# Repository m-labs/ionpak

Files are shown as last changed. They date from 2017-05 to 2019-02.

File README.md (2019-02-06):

ionpak
======

A modern, low-cost universal controller for hot-cathode ionization vacuum gauges.

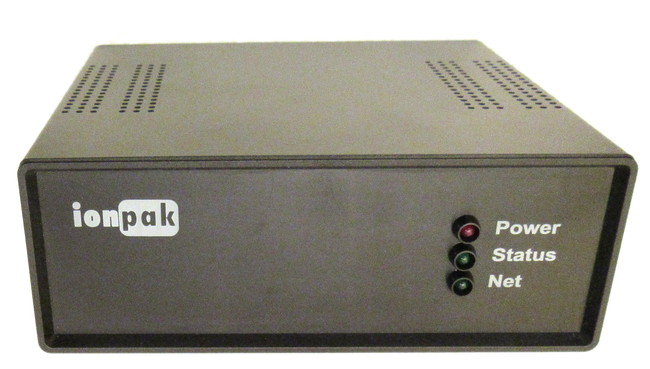
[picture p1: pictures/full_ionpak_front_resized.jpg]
ionpak picture


Why?
----

Many physics experiments require a good vacuum and therefore tools to diagnose vacuum-related problems. Ionization gauges provide a way to measure pressures in the medium to ultra-high vacuum regimes.

While the gauges themselves can be procured quite easily, the controller situation is more problematic. Existing commercial and DIY solutions have one or more of the following issues:

 * expensive
 * proprietary
 * poor performance at low (pA) collector currents
 * designed with obsolete components and overly bulky
 * lack of gauge voltage/current programmability
 * no/poor connectivity to a logging database
 * poor design and construction

The ionpak features:

 * a single-board low-cost design with modern components
 * open hardware and software
 * sub-pA electrometer performance
 * configurable voltages and emission current to adapt to various gauges
 * Ethernet connectivity

Where to find ionization vacuum gauges?
---------------------------------------

For medium and high vacuum, Chinese gauges can be ordered on Taobao under references ZJ-27 and ZJ-10. The Chinese for ionization gauge is 电离规. Those gauges have a simple construction and an extremely low cost, under USD 10 for glass tubulated models (requires flameworking) and a few times that price for flange-mounted ones. Those manufactured by [Chengdu Zhenghua](http://www.zhvacuum.com) appear to work satisfactorily, and glass gauges arrive sealed under vacuum (around 10⁻⁵ to 10⁻⁶ mbar) so they can be tested immediately. Ceramic sockets for the gauges can often be ordered from the same Taobao vendor.

For ultra-high vacuum, you can use G8130 from KJLC, which is pricy but of excellent quality. There is a lower-cost Bayard-Alpert Chinese gauge ZJ-12, of dubious quality for those pressure ranges, and with 2.5x less sensitivity than the KJLC part.

A low-cost source of quality UHV gauges remains to be found. You can try eBay, but the condition of the items is highly random.

How to connect the gauge?
-------------------------

The collector must be connected with a shielded (e.g. coaxial) cable. If the gauge has a metallic body (e.g. gauges mounted on CF flanges), connect the shield of the cable to the body, so that current from the high voltage electrodes will not leak into the collector electrode. This should not cause any ground loop in your system, as the gauge circuits inside the ionpak are galvanically isolated from its power input and from its Ethernet connector.

If a single cable is used for the filament and anode connections, the anode wire must be particularly well insulated from the filament wires, to avoid leakage currents that can be significant when the gauge is operated with a low emission (100µA or less) and influence the measurement result.

"Domino" terminal blocks from the local hardware store, with the plastic removed, can be used to connect the cables to the pins of CF-flanged gauges. Female circular contacts, such as Amphenol AT62-16-0122, are a nicer alternative but are slightly harder to find.

For baked systems, use PTFE insulated cables that can withstand 200°C. Operating the gauge during bake-out can remove the need to degas it (see the paper [Comments on the stability of B-A ionization gages](https://www.nist.gov/sites/default/files/documents/calibrations/jv13-2.pdf)).

It is a good idea to attach the cables to the vacuum system with a strap to avoid damaging the gauge by accidentally pulling on the cables, and to place a cover onto the pins to reduce the electrical shock hazard from the high voltage. Preferably those items should be made of metal so that they can be left on during bakeout.

Using the ionpak
----------------
Connect the ionpak to a firewalled Ethernet network *only*, as it does not provide authentication over the network.

The ionpak has a static IP address that defaults to `192.168.69.1`. It has a self-explanatory web interface that you can access by pointing your browser to [http://192.168.69.1](http://192.168.69.1). By default, the controller is disabled and the ionpak will not produce any output voltages; use the web interface to input your gauge settings and enable the controller.

The IP address, along with all the other configuration options, can be reset to the defaults by holding the pushbutton while the ionpak is powering up. The status LED will flash rapidly to acknowledge the configuration reset.

In addition to displaying its measurement results in the web interface, the ionpak exports them in the JSON format. The results are very straightforward to access from Python:

```
>>> import requests
>>> import json
>>> json.loads(requests.get("http://192.168.69.1/measure.json").text)
{'pressure': 3.8e-06, 'current': 3.357e-08}
```

In the JSON document, `pressure` is expressed in millibars and `current` (through the collector input) is expressed in amperes.

Warning
-------

Ionization gauges use dangerous voltages and the ionpak is capable of delivering a lethal amount of power. Be careful and use at your own risk.

Building and loading the firmware
---------------------------------

```sh
cd firmware
cargo build --release
openocd -f openocd.cfg
```

License
-------

Copyright 2017 M-Labs Limited.

License TBD, probably will be CERN OHL and GPL.

Pictures in the ``pictures`` folder, except ``proto_rev1.jpg``, are copyright Michelle Poon and not free.

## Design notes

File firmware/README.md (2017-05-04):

ionpak
======

A modern, low-cost universal controller for ionization vacuum gauges.

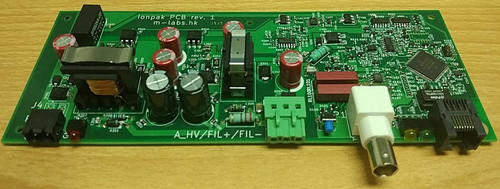
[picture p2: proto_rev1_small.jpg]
Prototype picture


Building and loading the firmware
---------------------------------

```sh
openocd -f support/openocd.cfg
xargo build --release
arm-none-eabi-gdb -x support/load.gdb target/thumbv7em-none-eabihf/release/ionpak-firmware
```

Flyback transformer construction
--------------------------------

TR300: Use EPCOS coilformer B66208X1010T1. Wind 5 turns on the primary and spread them across the length of the coilformer - it is particularly important that the air gap between the cores is covered by windings. Wind 70 turns on the secondary in multiple layers. As with all flyback transformers, the polarity of the windings is critical. Assemble with EPCOS cores B66317G500X127 and B66317GX127 (one half gapped core, one half ungapped core), and corresponding clips.

TR350: Use EPCOS coilformer B66206W1110T1 and cores B66311G250X127 and B66311GX127. Both the primary and the secondary have 5 turns and must be wound together, interleaving the windings. The same remarks as for TR300 apply.

Errata
------

PCB rev 1:

* R307 needs more clearance from D400
* Pins 1 and 12 of U502 need pull-downs
* Pin 1 of U501 needs pull-up
* D203 reversed polarity
* R236 and R234 are swapped
* Q301 needs to be NPN, change to BC817
* increase R307 -> 3.3Kohm and increase R300 -> 33Kohm
* C201: oscillates at 0 and 1nF, stable at 100nF
* add clamp diodes to GND on op-amp outputs to ADC when op-amp has negative supply
* R214 -> 4.7k
* LM339PT is in TSSOP package. Change for SOIC P/N
* GDT200 minimum firing voltage is too low
* the relay model should be changed to 9001-05-00. 9001-05-02 is an undocumented normally closed variant.

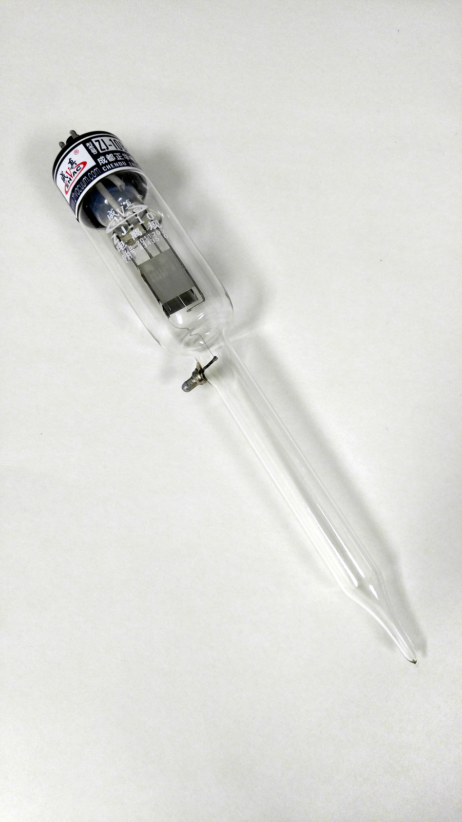
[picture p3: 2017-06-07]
pictures/zj10.jpg

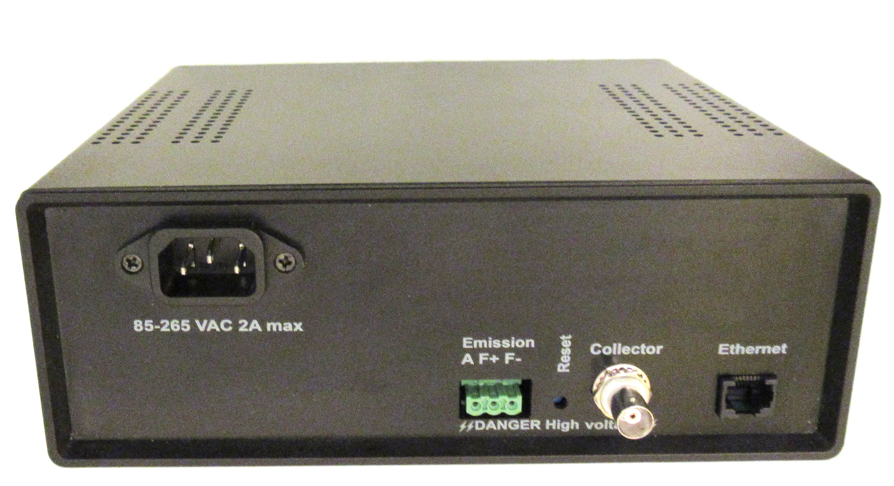
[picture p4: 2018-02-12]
pictures/full_ionpak_back.jpg

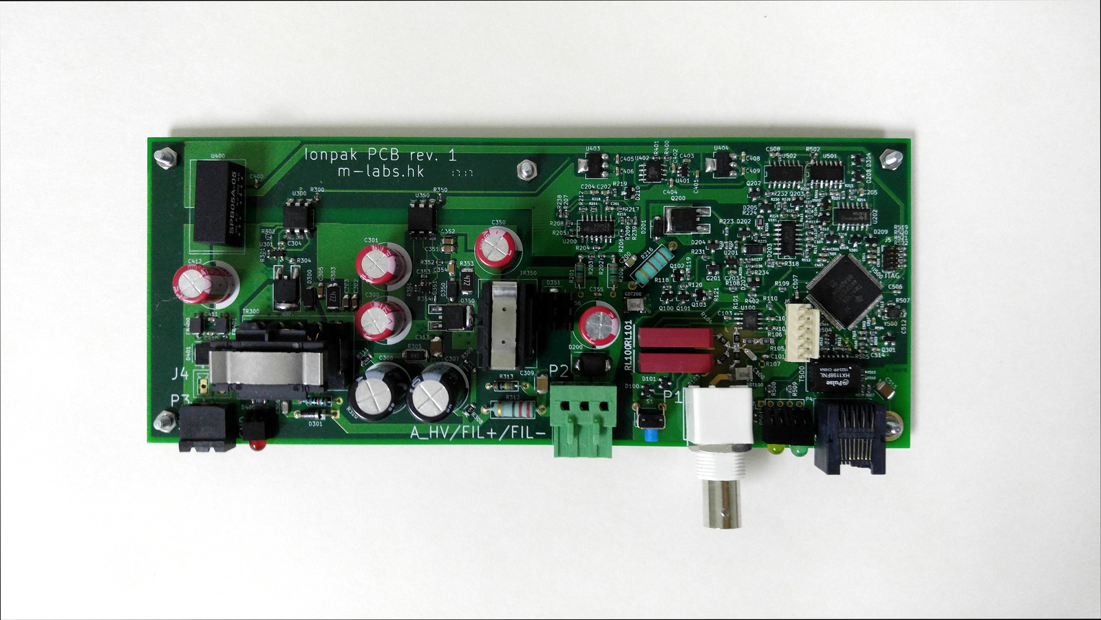
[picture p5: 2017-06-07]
pictures/pcb_1.jpg

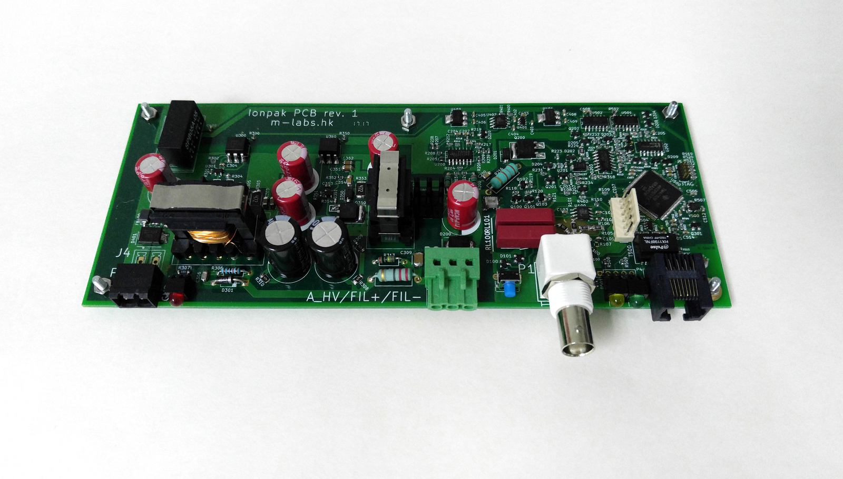
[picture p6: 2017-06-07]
pictures/pcb_2.jpg

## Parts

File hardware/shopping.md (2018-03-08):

* OLED display: https://world.taobao.com/item/539889688448.htm
* power supply modules: https://world.taobao.com/item/542931734858.htm

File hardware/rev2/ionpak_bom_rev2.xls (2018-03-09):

N | Refs | Value | Footprint | QTY | MFR | MPN | SPR | SPN
1 | C100 | 47pF/1206 | proj_footprints:C_1206_ns | 1 | AVX | 12062A101JAT2A |  | 478-1430-1-ND
2 | C102;C104;C201;C205;C304;C353;C355;C410;C411;C504;C509;C510;C505;C506;C507;C508;C503;C502;C103;C101;C414;C514 | 0.1uF | Capacitors_SMD:C_0603 | 22 | Murata | GRM188R71C104JA01D |  | 490-9731-1-ND
3 | C200 | 10000pF/1206 | Capacitors_SMD:C_1206 | 1 | Murata | GRM31BR72J103KW01L |  | 490-3512-1-ND
4 | C202;C204 | 1uF | Capacitors_SMD:C_0603 | 2 | Murata | GRM188R60J105KA01J |  | 490-6404-1-ND
5 | C302;C303;C352;C351 | 10uF/25V/1206 | Capacitors_SMD:C_1206 | 4 | Samsung Electro-Mechanics America, Inc. | CL31A106KAHNNNE |  | 1276-1075-1-ND
6 | C305;C354 | 0.1uF/100V/1206 | Capacitors_SMD:C_1206 | 2 | Murata | GRJ319R72A104KE11L |  | 490-10931-1-ND
7 | C306 | 10pF/1206 | Capacitors_SMD:C_1206 | 1 | Samsung Electro-Mechanics America, Inc. | CL31C100JIFNNNE |  | 1276-3195-1-ND
8 | C307;C308 | 10uF/450V | Capacitors_THT:C_Radial_D14_L25_P5 | 2 | Nichicon | UVR2W100MHD1TO |  | 493-12876-1-ND
9 | C309;C515 | 2200pF/2kV/1812 | Capacitors_SMD:C_1812 | 2 | Kemet | C1812C222KGRACTU |  | 399-7120-1-ND
10 | C357 | 100pF | Capacitors_SMD:C_0603 | 1 | Murata | GRM0335C1E101JA01D |  | 490-3160-1-ND
11 | C400;C402;C403;C401;C405;C406;C408;C409;C404;C511;C407 | 10uF | Capacitors_SMD:C_0603 | 11 | Murata | GRM188R60J106KE47D |  | 490-12538-1-ND
12 | C412;C350;C301;C356;C300 | 470uF/16V | Capacitors_THT:C_Radial_D13_L21_P5 | 5 | Panasonic Electronic Components | ECA-1CM471 |  | P5141-ND
13 | C500;C501 | 1000pF | Capacitors_SMD:C_0603 | 2 | Murata | GRM033R71C102KA01D |  | 490-6147-1-ND
14 | C512;C513 | 12pF | Capacitors_SMD:C_0603 | 2 | Murata | GRM0335C1E120JA01D |  | 490-3144-1-ND
15 | D200 | SMCJ7.5A | proj_footprints:DO-214AB | 1 | Diodes Incorporated | SMCJ7.5A-13-F |  | SMCJ7.5A-FDICT-ND
16 | D202 | BAS116 | proj_footprints:SOT-23 | 1 | Infineon Technologies | BAS116-7-F |  | BAS116-FDICT-ND
17 | D203 | SMAJ5.0A | proj_footprints:DO-214AC | 1 | Littelfuse Inc. | SMAJ5.0A |  | SMAJ5.0ALFCT-ND
18 | D210;D206 | BAT54S | proj_footprints:SOT-23 | 2 | ON Semiconductor | BAT54SLT1G |  | BAT54SLT1GOSCT-ND
19 | D211;D102;D306;D305;D304;D209;D208;D500;D100;D101 | BAT54 | proj_footprints:SOT-23 | 10 | ON Semiconductor | BAT54SLT1G |  | BAT54SLT1GOSCT-ND
20 | D300;D350;D201 | S1M | proj_footprints:DO-214AC | 3 | SMC Diode Solutions | S1MTR |  | 1655-1506-1-ND
21 | D301 | UF4007 | Diodes_THT:Diode_DO-41_SOD81_Horizontal_RM10 | 1 | SMC Diode Solutions | UF4007TA |  | 1655-1692-1-ND
22 | D351 | MBR1645 | proj_footprints:TO220AC | 1 | SMC Diode Solutions | MBR1060 |  | 1655-1022-ND
23 | D401 | SMCJ12A | proj_footprints:DO-214AB | 1 | Diodes Incorporated | SMCJ12A-13-F |  | SMCJ12A-FDICT-ND
24 | D501;D400 | LTL-533-11 | LEDs:LED_D3.0mm_Horizontal_O3.81mm_Z10.0mm | 2 | Lite-On Inc. | LTL-533-11 |  | 160-1977-ND
25 | D502 | LTL-523-11 | LEDs:LED_D3.0mm_Horizontal_O3.81mm_Z10.0mm | 1 | Lite-On Inc. | LTL-523-11 |  | 160-1976-ND
26 | D504 | SRV05-4 | proj_footprints:SOT-23-6 | 1 | SMC Diode Solutions | SRV05-4ATR |  | 1655-1653-1-ND
27 | FB401;FB400 | FB_10A | proj_footprints:28F0121-0SR-10 | 2 | Laird-Signal Integrity Products | 28F0121-0SR-10 |  | 240-2435-1-ND
28 | GDT100 | 2051-09 | proj_footprints:BOURNS-GDT-2051_ns | 1 | Bourns | 2051-09-SM-RPLF |  | 2051-09-SM-RPLFCT-ND
29 | GDT201 | 2035-09 | proj_footprints:BOURNS-GDT-2035TH | 1 | Bourns | 2035-09-BT1LF |  | 2035-09-BT1LFCT-ND
30 | GDT400 | 2057-35-BLF | proj_footprints:BOURNS-GDT-2035TH | 1 | Bourns | 2057-35-BLF |  | 2057-35-BLF-ND
31 | J4 | INT_PWR | Connectors_Phoenix:PhoenixContact_MCV-G_02x5.08mm_Vertical | 1 | Phoenix Contact | 1836299 |  | 277-6513-ND
32 | J5 | JTAG_ARM_10P | proj_footprints:Pin_Header_Straight_2x05_Pitch1.27mm | 1 | Sullins Connector Solutions | GRPB052VWVN-RC |  | S9015E-05-ND
33 | J6 | TTL-232R-3V3 | Pin_Headers:Pin_Header_Straight_1x06_Pitch2.54mm | 1 | Sullins Connector Solutions | SWR25X-NRTC-S06-ST-BA |  | S9414-ND
34 | J7 | EXT_LEDS | Pin_Headers:Pin_Header_Straight_1x05_Pitch2.54mm | 1 | Sullins Connector Solutions | SWR25X-NRTC-S04-ST-BA |  | S9410-ND
35 | J8 | I2C | Pin_Headers:Pin_Header_Straight_1x04_Pitch2.54mm | 1
36 | J9 | INT_FAN | Connectors_Molex:Molex_KK-6410-02_02x2.54mm_Straight | 1 | Molex | 22272021 |  | WM4111-ND
37 | L400 | SDR0503-101KL | Choke_SMD:Choke_SMD_Wuerth-WE-PD2-Typ-MS | 1 | Bourns Inc. | SDR0503-101KL |  | SDR0503-101KLCT-ND
38 | P1 | BNC | proj_footprints:bnc_90_1-1337543-0_ns | 1 | TE Connectivity AMP Connectors | 1-1337543-0 |  | A97553-ND
39 | P2 | CONN_01X03 | proj_footprints:PhoenixContact_1786417_03 | 1 | Phoenix Contact | 1786417 |  | 277-5985-ND
40 | P4 | RJ45_NO_SHIELD | proj_footprints:FCI_54601-908WPLF | 1 | Amphenol FCI | 54601-908WPLF |  | 609-5081-ND
41 | Q101;Q100;Q401 | DMG2305UX | proj_footprints:SOT-23 | 3 | Diodes Incorporated | DMG2305UX-13 |  | DMG2305UX-13DICT-ND
42 | Q103;Q102 | 2N7002 | proj_footprints:SOT-23 | 2 | Nexperia USA Inc. | 2N7002P,215 |  | 1727-4692-1-ND
43 | Q200 | FQD7N10L | proj_footprints:DPAK | 1 | Fairchild/ON Semiconductor | FQD7N10LTM |  | FQD7N10LTMCT-ND
44 | Q203;Q202;Q104 | DMN3404L | proj_footprints:SOT-23 | 3 | Diodes Incorporated | DMN3404L-7 |  | DMN3404LDICT-ND
45 | Q300;Q350 | IRFR3411 | proj_footprints:DPAK | 2 | Infineon Technologies | IRFR3411TRPBF |  | IRFR3411TRPBFCT-ND
46 | Q301 | BC817-40 | proj_footprints:SOT-23 | 1 | ON Semiconductor | BC81740MTF |  | BC81740MTFCT-ND
47 | Q400 | BC807-40 | proj_footprints:SOT-23 | 1 | ON Semiconductor | BC807-40LT1G |  | BC807-40LT1GOSCT-ND
48 | R101;R100 | 100K/1206 | proj_footprints:R_1206_ns | 2 | Yageo | RC1206JR-07100KL |  | 311-100KERCT-ND
49 | R102;R107 | 100K | Resistors_SMD:R_0603 | 2 | Yageo | RC0603JR-07100KL |  | 311-100KGRCT-ND
50 | R103 | 27K/1%/1206 | proj_footprints:R_1206_ns | 1 | Yageo | RC1206FR-0727KL |  | 311-27.0KFRCT-ND
51 | R104 | 5.1M/1%/1206 | proj_footprints:R_1206_ns | 1 | Yageo | RC1206FR-0727KL |  | 311-27.0KFRCT-ND
52 | R105;R106 | HMC1206JT500M | proj_footprints:R_1206_ns | 2 | Stackpole Electronics Inc. | HMC1206JT500M |  | HMC1206JT500MCT-ND
53 | R109;R108 | 33R | Resistors_SMD:R_0603 | 2 | Yageo | RC0603FR-0733RL |  | 311-33.0HRCT-ND
54 | R110;R208;R209;R228;R226 | 4.7K/1% | Resistors_SMD:R_0603 | 5 | Yageo | RC0603FR-074K7L |  | 311-4.70KHRCT-ND
55 | R111;R217;R218;R404;R405;R523;R524 | 1K | Resistors_SMD:R_0603 | 7 | Yageo | RC0603FR-071KL |  | 311-1.00KHRCT-ND
56 | R112;R117;R215;R221;R317;R318;R230;R223 | 10K/1% | Resistors_SMD:R_0603 | 8 | Yageo | RC0603FR-0710KL |  | 311-10.0KHRCT-ND
57 | R114;R220;R227 | 470R/1% | Resistors_SMD:R_0603 | 3 | Yageo | RC0603FR-07470RL |  | 311-470HRCT-ND
58 | R116;R229;R401;R400 | 240R/1% | Resistors_SMD:R_0603 | 4 | Yageo | RC0603FR-07240RL |  | 311-240HRCT-ND
59 | R120;R207;R210;R118;R500;R407;R408 | 33K | Resistors_SMD:R_0603 | 7 | Yageo | RC0603FR-0733KL |  | 311-33.0KHRCT-ND
60 | R121;R301;R351;R119;R501;R503;R522;R519;R520;R521;R320;R355;R510;R356 | 10K | Resistors_SMD:R_0603 | 14 | Yageo | RC0603FR-0710KL |  | 311-10.0KHRCT-ND
61 | R200;R201;R240 | 15M/1%/RNV | Resistors_ThroughHole:R_Axial_DIN0207_L6.3mm_D2.5mm_P10.16mm_Horizontal | 3 | Stackpole Electronics Inc. | RNV14FAL15M0 |  | RNV14FAL15M0CT-ND
62 | R203;R202 | 560K/1% | Resistors_SMD:R_0603 | 2 | Yageo | RC0603FR-07560KL |  | 311-560KHRCT-ND
63 | R204 | 1M/1% | Resistors_SMD:R_0603 | 1 | Yageo | RC0603FR-071ML |  | 311-1.00MHRTR-ND
64 | R206;R205 | 2.7M/1% | Resistors_SMD:R_0603 | 2 | Yageo | RC0603FR-072M7L |  | RC0603FR-072M7L-ND
65 | R212;R211;R214;R238;R239;R115;R113 | 7.5K/1% | Resistors_SMD:R_0603 | 7 | Yageo | RC0603FR-077K5L |  | 311-7.50KHRCT-ND
66 | R213;R319;R300;R350;R502;R508;R403;R509;R406 | 240R | Resistors_SMD:R_0603 | 9 | Yageo | RC0603FR-07240RL |  | 311-240HRCT-ND
67 | R216 | 180R/1W | Resistors_ThroughHole:R_Axial_DIN0414_L11.9mm_D4.5mm_P15.24mm_Horizontal | 1 | YAGEO | KNP100JR-73-180R |  | 180ACCT-ND
68 | R219 | 22K | Resistors_SMD:R_0603 | 1 | Yageo | RC0603FR-0722KL |  | 311-22.0KHRCT-ND
69 | R222;R504 | 100R | Resistors_SMD:R_0603 | 2 | Yageo | RC0603JR-07100RL |  | 311-100GRCT-ND
70 | R224 | 36R/1%/1206 | Resistors_SMD:R_1206 | 1 | Yageo | RC1206FR-0736RL |  | 311-36.0FRCT-ND
71 | R225 | 180R/1% | Resistors_SMD:R_0603 | 1 | Yageo | RC0603FR-07180RL |  | 311-180HRCT-ND
72 | R302;R352 | 3.3R | Resistors_SMD:R_0603 | 2 | Yageo | RC0603FR-073R3L |  | RC0603FR-073R3L-ND
73 | R303;R353 | 4.7K/2512 | Resistors_SMD:R_2512 | 2 | Yageo | RC2512JK-074K7L |  | YAG3405CT-ND
74 | R304;R354 | 0R | Resistors_SMD:R_0603 | 2 | Yageo | RC0603JR-070RL |  | 311-0.0GRCT-ND
75 | R305 | 2R/2512 | Resistors_SMD:R_2512 | 1 | Stackpole Electronics Inc. | RMCF2512JT2R00 |  | RMCF2512JT2R00CT-ND
76 | R306 | 10K/RNV | Resistors_ThroughHole:R_Axial_DIN0207_L6.3mm_D2.5mm_P10.16mm_Horizontal | 1 | Stackpole Electronics Inc. | RNF14FTD10K0 |  | RNF14FTD10K0CT-ND
77 | R307 | 3.3K/1206 | Resistors_SMD:R_1206 | 1 | Yageo | RC1206JR-073K3L |  | 311-3.3KERTR-ND
78 | R308;R309;R310;R311 | 470K/1206 | Resistors_SMD:R_1206 | 4 | Yageo | RC1206JR-07470KL |  | 311-470KERCT-ND
79 | R312 | 22R/1W | Resistors_ThroughHole:R_Axial_DIN0414_L11.9mm_D4.5mm_P15.24mm_Horizontal | 1 | YAGEO | KNP100JR-73-22R |  | 22ACCT-ND
80 | R313 | 2M/1%/RNV | Resistors_ThroughHole:R_Axial_DIN0207_L6.3mm_D2.5mm_P10.16mm_Horizontal | 1 | Stackpole Electronics Inc. | RNV14FAL2M00 |  | RNV14FAL2M00CT-ND
81 | R402 | 10R | Resistors_SMD:R_0603 | 1 | Yageo | RC0603JR-0710RL |  | 311-10GRCT-ND
82 | R505 | 4.87K/1% | Resistors_SMD:R_0603 | 1 | Yageo | RC0603FR-074K87L |  | 311-4.87KHRCT-ND
83 | R506 | 51R | Resistors_SMD:R_0603 | 1 | Yageo | RC0603FR-0751RL |  | 311-51.0HRCT-ND
84 | R507 | 2K | Resistors_SMD:R_0603 | 1 | Yageo | RC0603FR-072KL |  | 311-2.00KHRCT-ND
85 | R511;R512;R513;R514 | 49.9R | Resistors_SMD:R_0603 | 4 | Yageo | RC0603FR-0749R9L |  | 311-49.9HRCT-ND
86 | R515;R516;R517;R518 | 75R | Resistors_SMD:R_0603 | 4 | Yageo | 311-75.0HRCT-ND |  | RC0603FR-0775RL
87 | R525 | 15M/RNV | Resistors_ThroughHole:R_Axial_DIN0207_L6.3mm_D2.5mm_P10.16mm_Horizontal | 1 | Stackpole Electronics Inc. | RNV14FAL15M0 |  | RNV14FAL15M0CT-ND
88 | RL101;RL100 | 9001-05-00 | proj_footprints:COTO-9001_ns | 2 | COTO | 9001-05-00 |  | 306-1055-ND
89 | S1 | SW_PBTN_2PIN_V | proj_footprints:SW_Tactile_SKHH_Angled_v | 1 | TE Connectivity ALCOSWITCH Switches | 1825027-8 |  | 450-1657-ND
90 | T500 | HX1198FNL | proj_footprints:H2019FNL | 1 | Pulse Electronics Corporation | HX1198FNL |  | 553-2201-ND
91 | TR300 | TDK_B66208X | proj_footprints:TDK_B66208X | 1 |  | TranformerFl |  | custom
92 | TR350 | TDK_B66206X | proj_footprints:TDK_B66206X | 1 |  | TransformerHV |  | custom
93 | U100 | LMP7721 | proj_footprints:SOIC-8-N_ns | 1 | Texas Instruments | LMP7721MA/NOPB |  | LMP7721MA/NOPB-ND
94 | U101;U200 | TSV324A | SMD_Packages:SOIC-14_N | 2 | STMicroelectronics | TSV324IDT |  | 497-8198-1-ND
95 | U202 | LM339ADT | SMD_Packages:SOIC-14_N | 1 | STMicroelectronics | LM339ADT |  | 497-1586-2-ND
96 | U300;U350 | H11L | proj_footprints:6-SMD | 2 | Everlight Electronics Co Ltd | H11L1S(TA) |  | 1080-1201-1-ND
97 | U301;U351 | FAN3100C | proj_footprints:SOT-23-5 | 2 | Fairchild/ON Semiconductor | FAN3100CSX |  | FAN3100CSXCT-ND
98 | U400 | SPB05A-05 | proj_footprints:SPB05A | 1 | Mean Well | SPB05A-05 |  | Mouser/Taobao
99 | U401 | LM2664 | proj_footprints:SOT-23-6 | 1 | Texas Instruments | LM2664M6/NOPB |  | LM2664M6/NOPBCT-ND
100 | U402 | LM337L | SMD_Packages:SOIC-8-N | 1 | Texas Instruments | LM337LMX |  | LM337LMXCT-ND
101 | U403 | AMS1117-3.0 | proj_footprints:SOT-223 | 1 | Texas Instruments | TLV1117LV30DCYR |  | 296-30591-1-ND
102 | U404 | AMS1117-3.3 | proj_footprints:SOT-223 | 1 | Diodes Incorporated | AZ1117IH-3.3TRG1 |  | AZ1117IH-3.3TRG1DICT-ND
103 | U405 | LTV-817S | proj_footprints:OPTO-SMD4 | 1 |  | LTV-817S-TA1 |  | 160-1893-1-ND
104 | U500 | TM4C1294KCPDT | proj_footprints:TQFP-128 | 1 | Texas Instruments | TM4C1294KCPDTI3R |  | 296-43659-1-ND
105 | U501;U502 | 74HC00 | SMD_Packages:SOIC-14_N | 2 | Diodes Incorporated | 74HC00S14-13 |  | 74HC00S14-13DICT-ND
106 | Y500 | 25MHz | proj_footprints:XTAL3_2X2_5 | 1 | NDK America, Inc. | NX3225GA-25.000M-STD-CRG-2 |  | 644-1259-1-ND

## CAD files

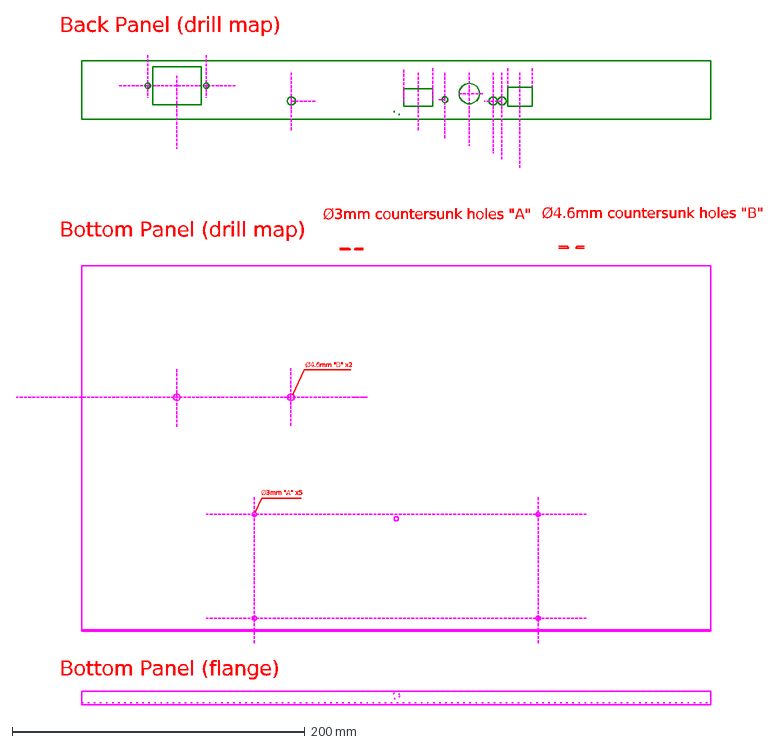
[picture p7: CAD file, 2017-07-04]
hardware/mechanical/Ionpak_1U_v5b.dxf
Bottom Panel (drill map)
Back Panel (drill map)
Bottom Panel (flange)
Ø4.6mm countersunk holes "B"
Ø3mm countersunk holes "A"
Ø4.6mm "B" x2
Ø3mm "A" x5

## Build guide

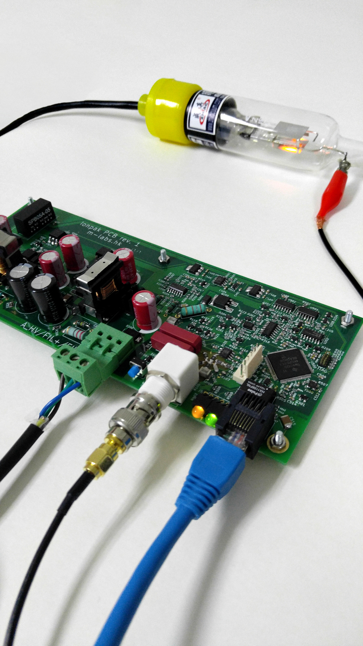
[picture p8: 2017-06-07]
pictures/setup2.jpg

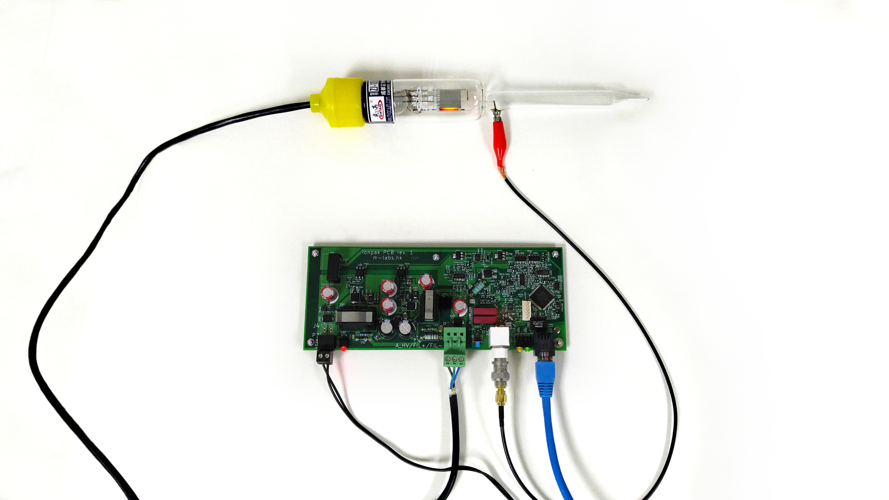
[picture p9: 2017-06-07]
pictures/setup1.jpg

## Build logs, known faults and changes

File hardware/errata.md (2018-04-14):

Hardware errata
===============

Rev 1
-----

* R307 needs more clearance from D400
* Pins 1 and 12 of U502 need pull-downs
* Pin 1 of U501 needs pull-up
* D203 reversed polarity
* R236 and R234 are swapped
* Q301 needs to be NPN, change to BC817
* increase R307 -> 3.3Kohm and increase R500 -> 33Kohm
* C201: oscillates at 0 and 1nF, stable at 100nF
* add clamp diodes to GND on op-amp outputs to ADC when op-amp has negative supply
* R214 -> 7.5k
* LM339PT is in TSSOP package. Change for SOIC P/N
* GDT200 minimum firing voltage is too low
* the relay model should be changed to 9001-05-00. 9001-05-02 is an undocumented normally closed variant.
* D504 should follow the schematics in its datasheet
* R502 should be connected to VCC
* R502 -> 240 ohm
* C500 -> 1nF
* R234 -> 7.5k
* Q104 -> DMN3404
* R114 -> 470 ohm
* R115 -> 4.7k
* R227 -> 470 ohm
* R228 -> 4.7k
* review values of R226 and R113
* C100 -> 47pF NP0 AVX, R107 -> 100K, C101 -> 0.1uF
* use crystal type recommended by the MCU datasheet
* add connector for OLED display?
* enlarge holes to fit M3 screws comfortably
* add 15M resistor between A and FIL-
* power U200 from a small negative voltage instead of GND
* review choice of filament flyback output diode
* invert LED position so that the Ethernet LED is closest to the connector
* invert polarity of LEDs (Ethernet LED polarity cannot be programmed)
* change D351 model to MBR1645
* add snubber on D351
* add heatsink (Seifert-KK633) to D351
* move D351 further away from transformer for heatsink clearance
* add plated-through holes and pads for mounting rods of BNC connector
* simplify FBI circuit, 2 ranges only (typ. 8mA and 45mA), remove diodes and neglect MOSFET leakage
* to support different case designs, replace the holes on the connectors side with slots. One of the case designs requires holes whose center is at 11.5mm from the board edge.
* review choice of external LED connector type and clearance
* if using a non-polarized connector, change pinout so that connecting the LEDs the wrong way cannot cause damage
* add 12V fan connector and on/off circuit (with optocoupler)
* increase sensitivity to ~20fA / LSB

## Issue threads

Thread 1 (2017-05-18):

measure leakage currents

sbourdeauducq, 2017-05-18:
The firmware can test the system for leakage currents by turning the HV on with the filament off.

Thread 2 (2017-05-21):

FPU does not work outside interrupt handler

sbourdeauducq, 2017-05-21:
The cortex-m code that enables the FPU is incorrect, but fixing it (https://github.com/sbourdeauducq/cortex-m/commit/cc21af24c8eb0b890b7b1b88f8d85dcea9848991) does not seem to help.

Closed 2017-06-12.

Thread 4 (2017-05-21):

ADC stops sampling after a few dozen seconds

sbourdeauducq, 2017-05-21:
According to @whitequark: The core isn't running fast enough for 32 MHz ADC clock, should go away with the PWM reclocking/resolution increase (#3).

whitequark, 2017-06-09:
did you solve this?

sbourdeauducq, 2017-06-09:
Yes, Alexander did, but I have not committed the fix yet.

Closed 2017-06-09.

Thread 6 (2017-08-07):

print message on UART before switching to xtal oscillator

sbourdeauducq, 2017-08-07:
To check if MCU is alive during production tests.

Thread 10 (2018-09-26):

Status of firmware

lweisef, 2018-09-26:
Hi,
I hope I am asking my questions in the right place here.
I am considering using the controller for my ion gauges. Before actually building the controller I would like to know the status of the firmware so that I can estimate how much time I would need to implement the features I need. I am new to rust so I might have overlooked something, so please correct me if I am wrong.
It looks to me like:
- the settings for the gauge and the current/pressure conversion are hardcoded
- the measurement starts immediately after initialisation and more importantly cannot be stopped on demand

I have another question for those already running an ionpak:
The collector current is averaged 64x by the ADC and another 512x by the firmware. Is so much averaging really neccessary, does the readout fluctuate that much?
Background of this question: Ideally I would like to control valves and pumps based on the readings of the ionpak. For some cases a 100ms reaction time would be too slow.

Thanks a lot
Lukas

sbourdeauducq, 2018-09-27:
> I am considering using the controller for my ion gauges.

Great! What application do you have in mind?

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

Correct. The firmware is still very much in a proof-of-concept stage at the moment.

> I have another question for those already running an ionpak:
> The collector current is averaged 64x by the ADC and another 512x by the firmware. Is so much averaging really neccessary, does the readout fluctuate that much?

No. Some averaging is necessary, but 512 is only a value that I threw in there without much research. It should be possible to optimize it.

Speaking of fluctuations, the PID control of the emission is rather unstable; there is some literature on this issue (the emission characteristic is highly non-linear) but I have had no time to look into it.

> Background of this question: Ideally I would like to control valves and pumps based on the readings of the ionpak. For some cases a 100ms reaction time would be too slow.

Note that the bandwidth of the TIA on the highest gain setting is also low, and this may limit the reaction time if you are doing ultra-high vacuum.

lweisef, 2018-09-27:
Thanks you very much for the detailed answer.

> Great! What application do you have in mind?

Basically I want to replace some commercial controllers whose electronics sometimes produce unstable results. The vacuum system has a pressure between 8*10^-9 and 2*10^-5 mbar under normal conditions. The valves I want to switch based on the pressure readings should prevent the system from completely venting in case of "non-normal" conditions. A reaction time of a few ms should be sufficient.

> Speaking of fluctuations, the PID control of the emission is rather unstable; there is some literature on this issue (the emission characteristic is highly non-linear) but I have had no time to look into it.

Looking through the code I found, that the result of the PIDs of the cathode does not seem to be used, but a constant PWM duty cycle is set:
[https://github.com/m-labs/ionpak/blob/89104a551c55553120ca00c391e653f96a752ff6/firmware/src/loop_cathode.rs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](url)
But it might also be a debugging artefact.

sbourdeauducq, 2018-09-27:
> But it might also be a debugging artefact.

Yes, that should not have been committed.

sbourdeauducq, 2018-09-27:
Out of curiosity, what is that vacuum system for?

lweisef, 2018-09-27:
The system is for angular resolved photoelectron measurements on size selected clusters. The ion gauges are connected to the time of flight spectrometer that separates different cluster sizes and to the cluster and electron detector.

lweisef, 2018-10-01:
Today we discussed in our group meeting if we want to use an ionpak controller. I would probably be able to implement the features I am missing but I lack the knowledge and time to work on the unstable emission. So I would wait until the emission issue is fixed. Should I close this issue?

sbourdeauducq, 2018-10-02:
Please email me at sb at m-labs.hk and let's discuss this further.

Closed 2018-10-02.

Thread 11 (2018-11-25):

Provide 1mA current limit and enforce it in hardware

DemiMarie, 2018-11-25:
My understanding is that an ionization gague current is typically measured in μA or below, so a current of over 1mA indicates a fault condition and the device should be shut down.  The only possible exception is at power-up, when parasitic capacitance needs to be charged.

More importantly, this provides a critical safety feature: by enforcing a 1mA current limit, the hazard of electric shock is significantly reduced, though by no means eliminated.

The limit should be enforced entirely in hardware.

sbourdeauducq, 2018-11-25:
Which current? The emission current can definitely be higher than 1mA.

Closed 2018-11-26.

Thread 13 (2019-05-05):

Is the gauge_settings.html file missing ?

VeryBitter, 2019-05-05:
Hi
I am thinking of giving it a go to this gauge controller! Looks very promising (and cheap) to me). I work with MBE in an academic research centre. Do you have some estimation for the time it takes to solder all the components?

Looking at the software folder, it seems to me that the "gauge_settings.html" file is missing. Isn't it?

Great job you have done!

sbourdeauducq, 2019-05-05:
Yep, it is missing. Thanks for your interest, but before you get too excited, I have to point out that this project is still in at an early stage of development and that I generally lack time to work on it. So, there are many important things that are currently missing, such as that page. If you're willing to help out, it would be great :)

VeryBitter, 2019-05-05:
Thanks for the swift answer! I could try to help. But first I will have to test my soldering skills!

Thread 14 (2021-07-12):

Correct version of code posted?

bynars99, 2021-07-12:
It looks like the currently posted code is an old version, corresponding to the Rev 1 hardware, since the code mentions three FBI range settings. It also looks like it has some values overridden with hardcoded ones, such as the fv_pwm_duty on line 100-101 in loop_cathode.rs.

Is it possible to get the latest code?

Closed 2021-07-12.

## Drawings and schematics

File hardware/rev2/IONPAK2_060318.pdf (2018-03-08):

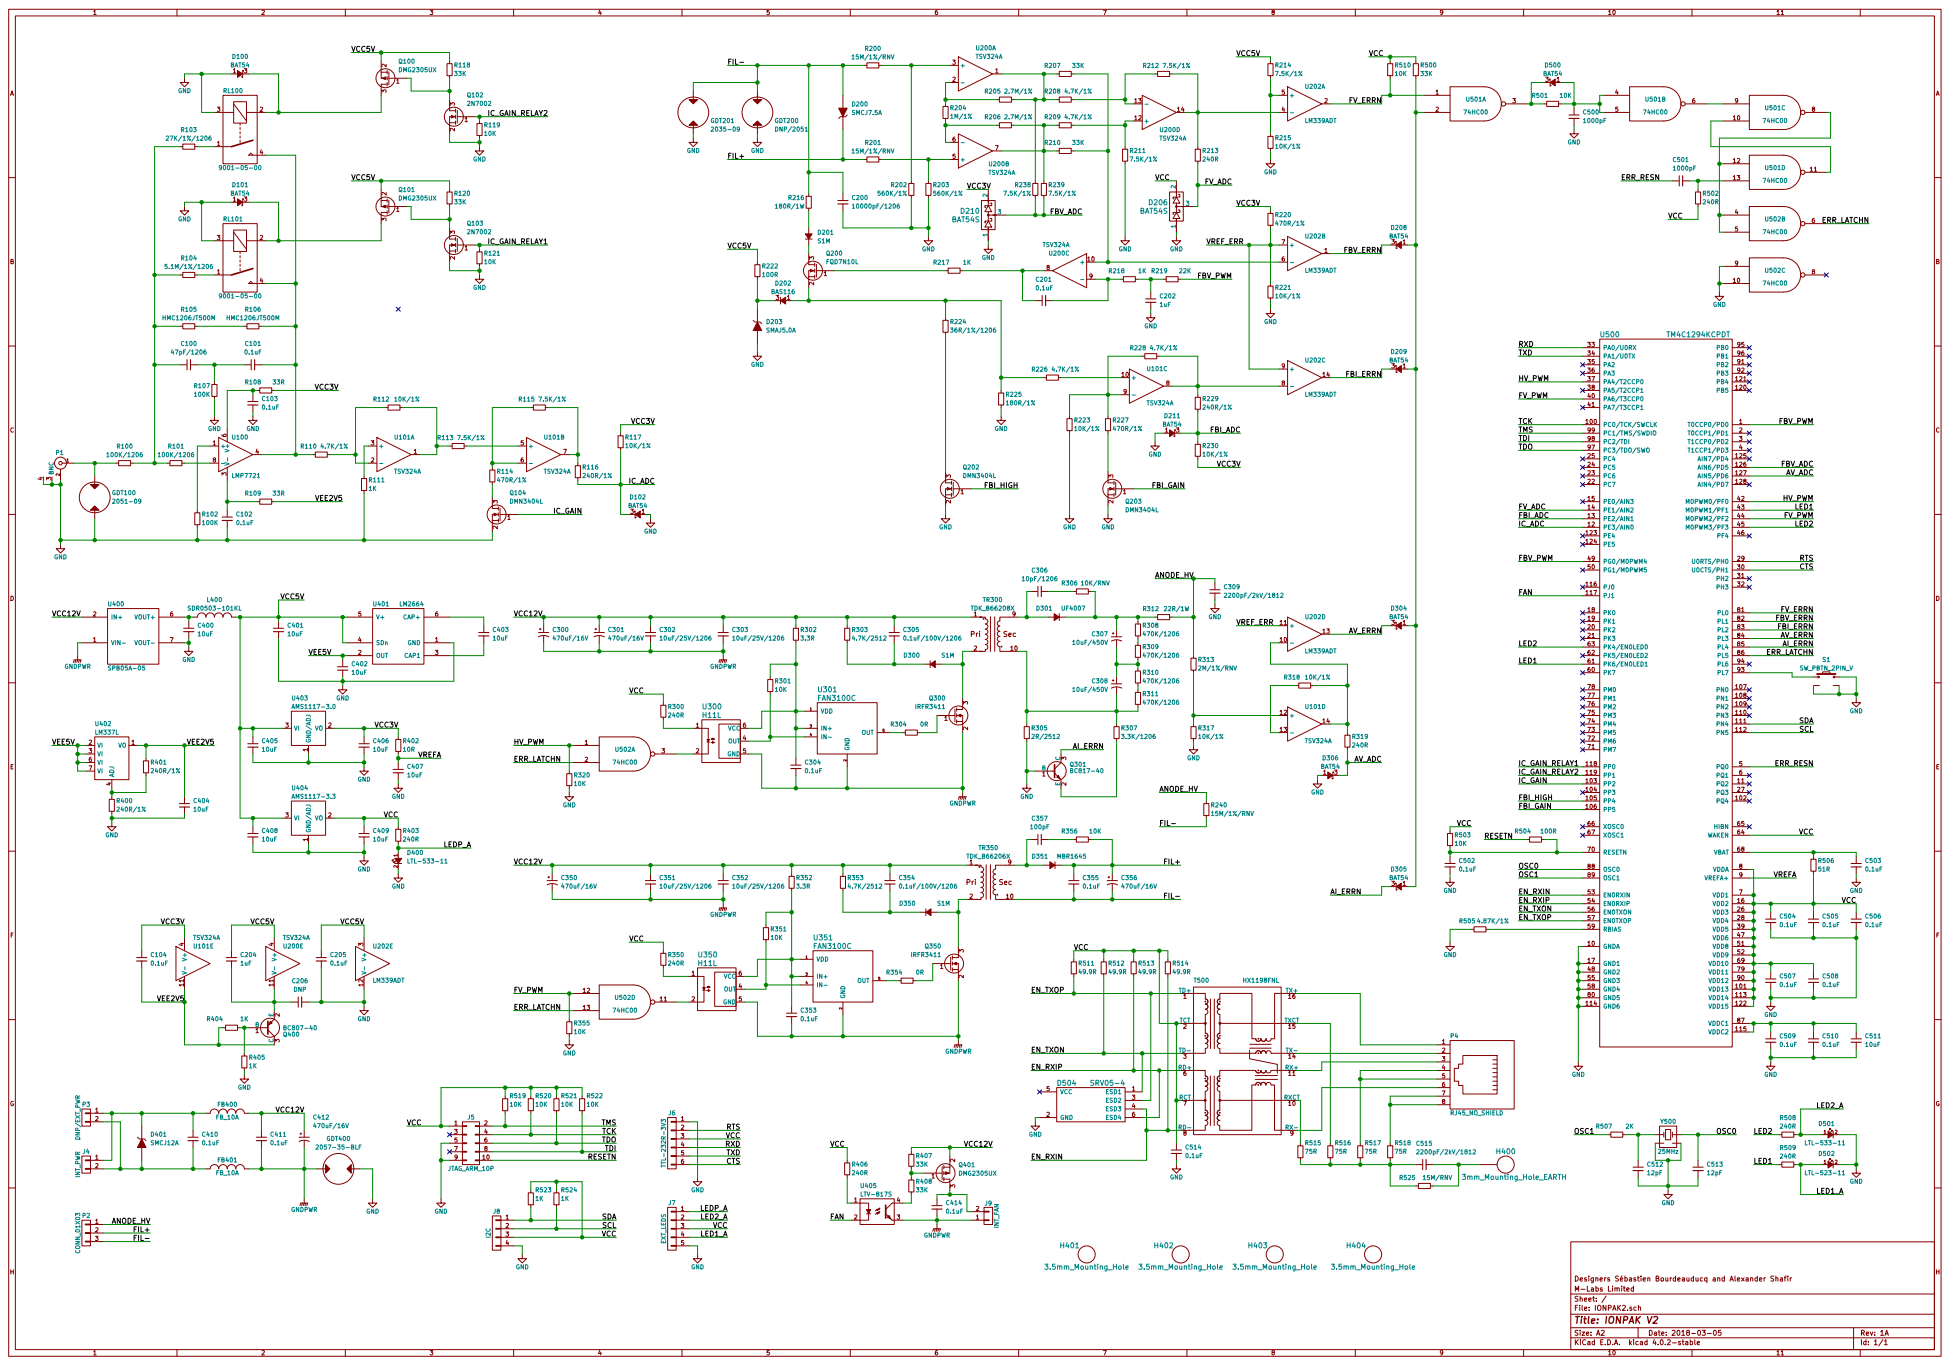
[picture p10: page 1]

File: IONPAK2.sch Sheet: / M-Labs Limited Designers Sébastien Bourdeauducq and Alexander Shafir V- 3 V+

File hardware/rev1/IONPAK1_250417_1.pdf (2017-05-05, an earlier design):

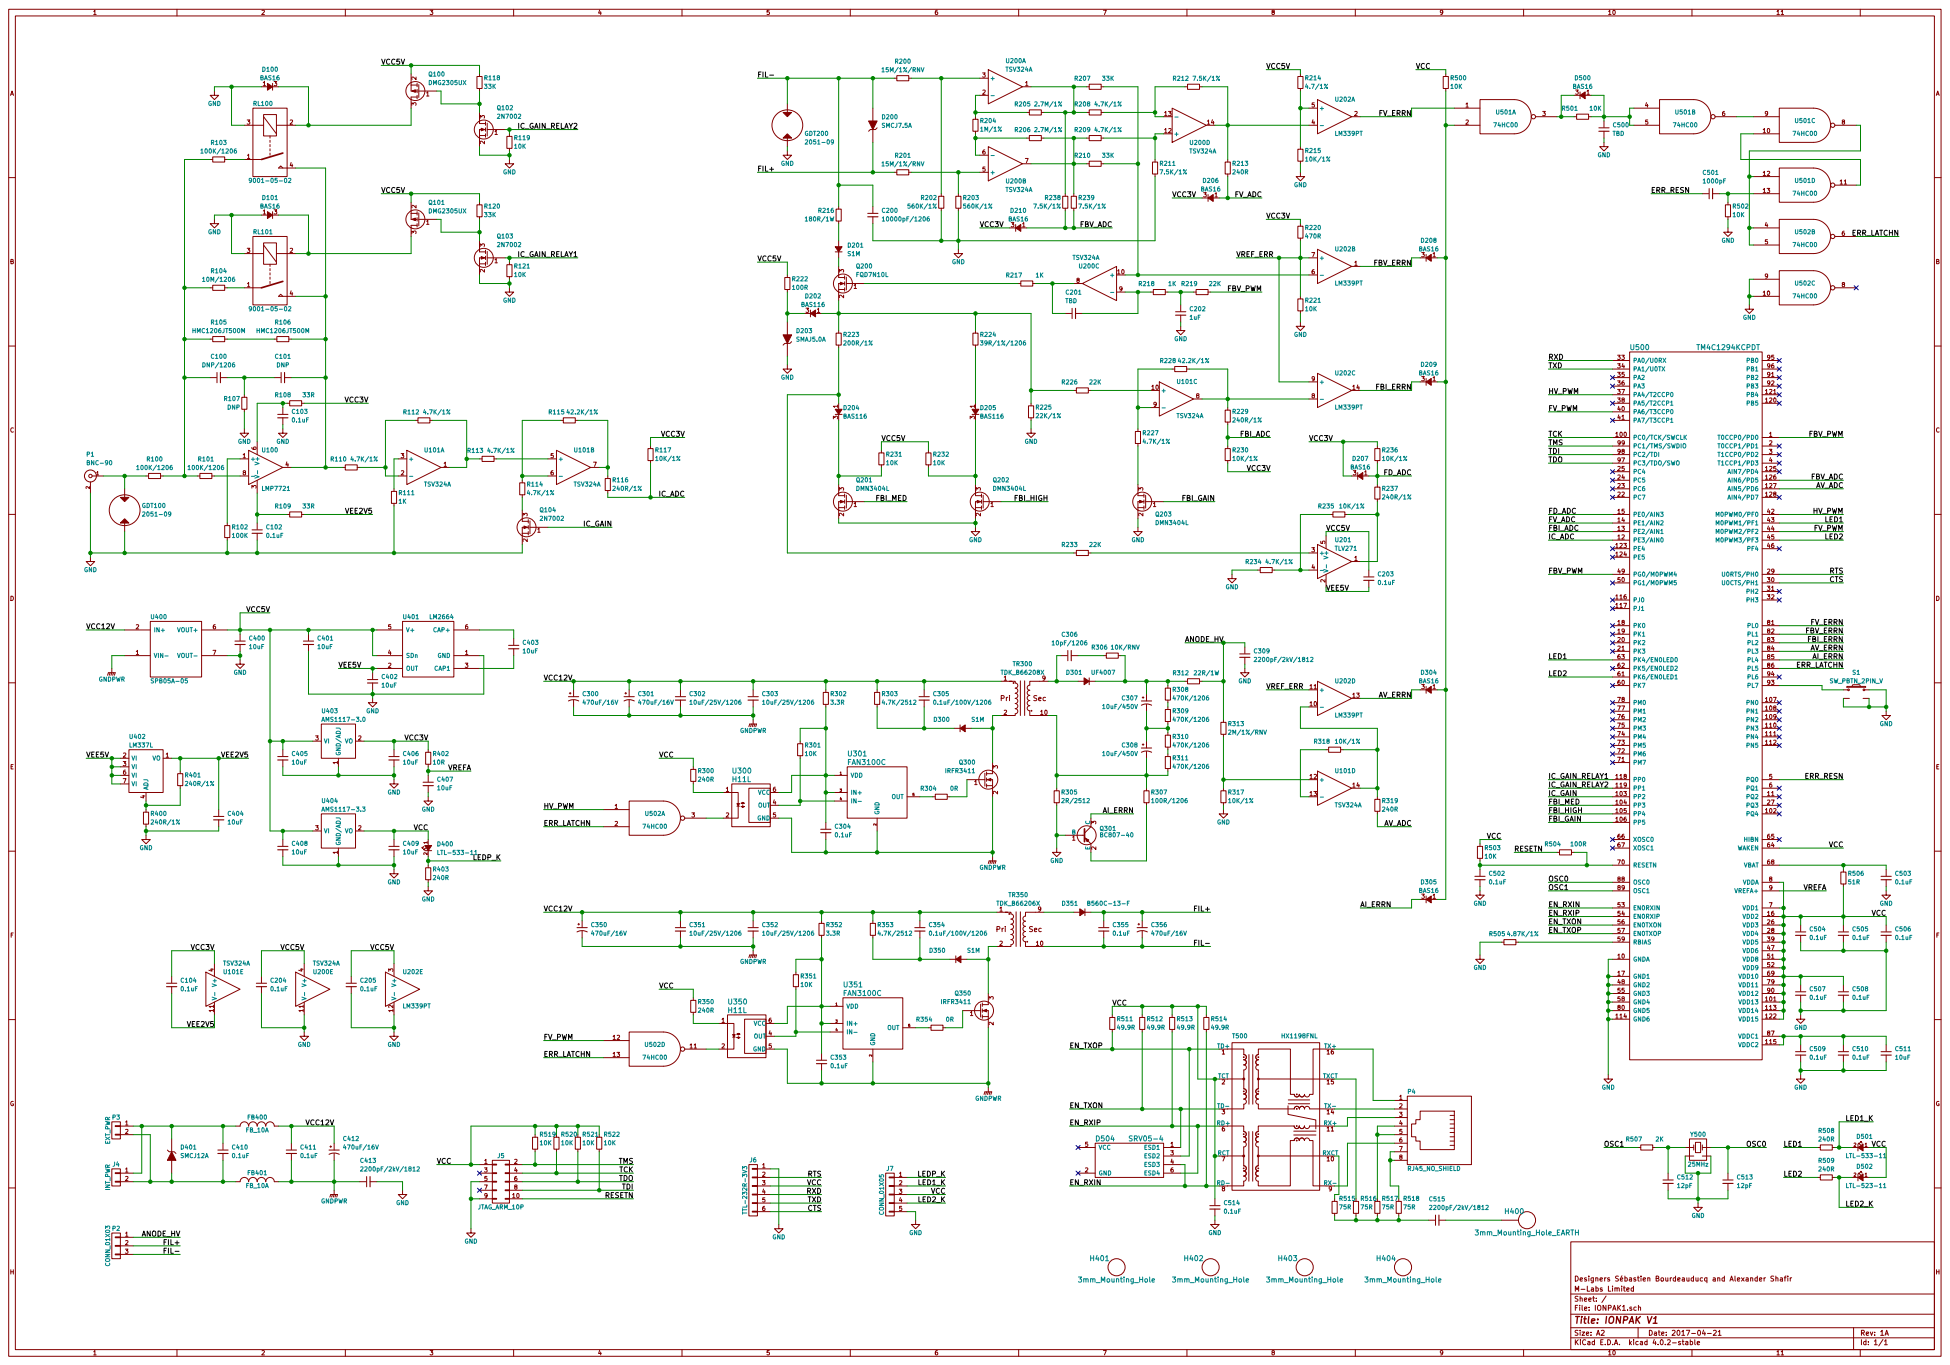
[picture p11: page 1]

File: IONPAK1.sch Sheet: / M-Labs Limited Designers Sébastien Bourdeauducq and Alexander Shafir V- 3 V+

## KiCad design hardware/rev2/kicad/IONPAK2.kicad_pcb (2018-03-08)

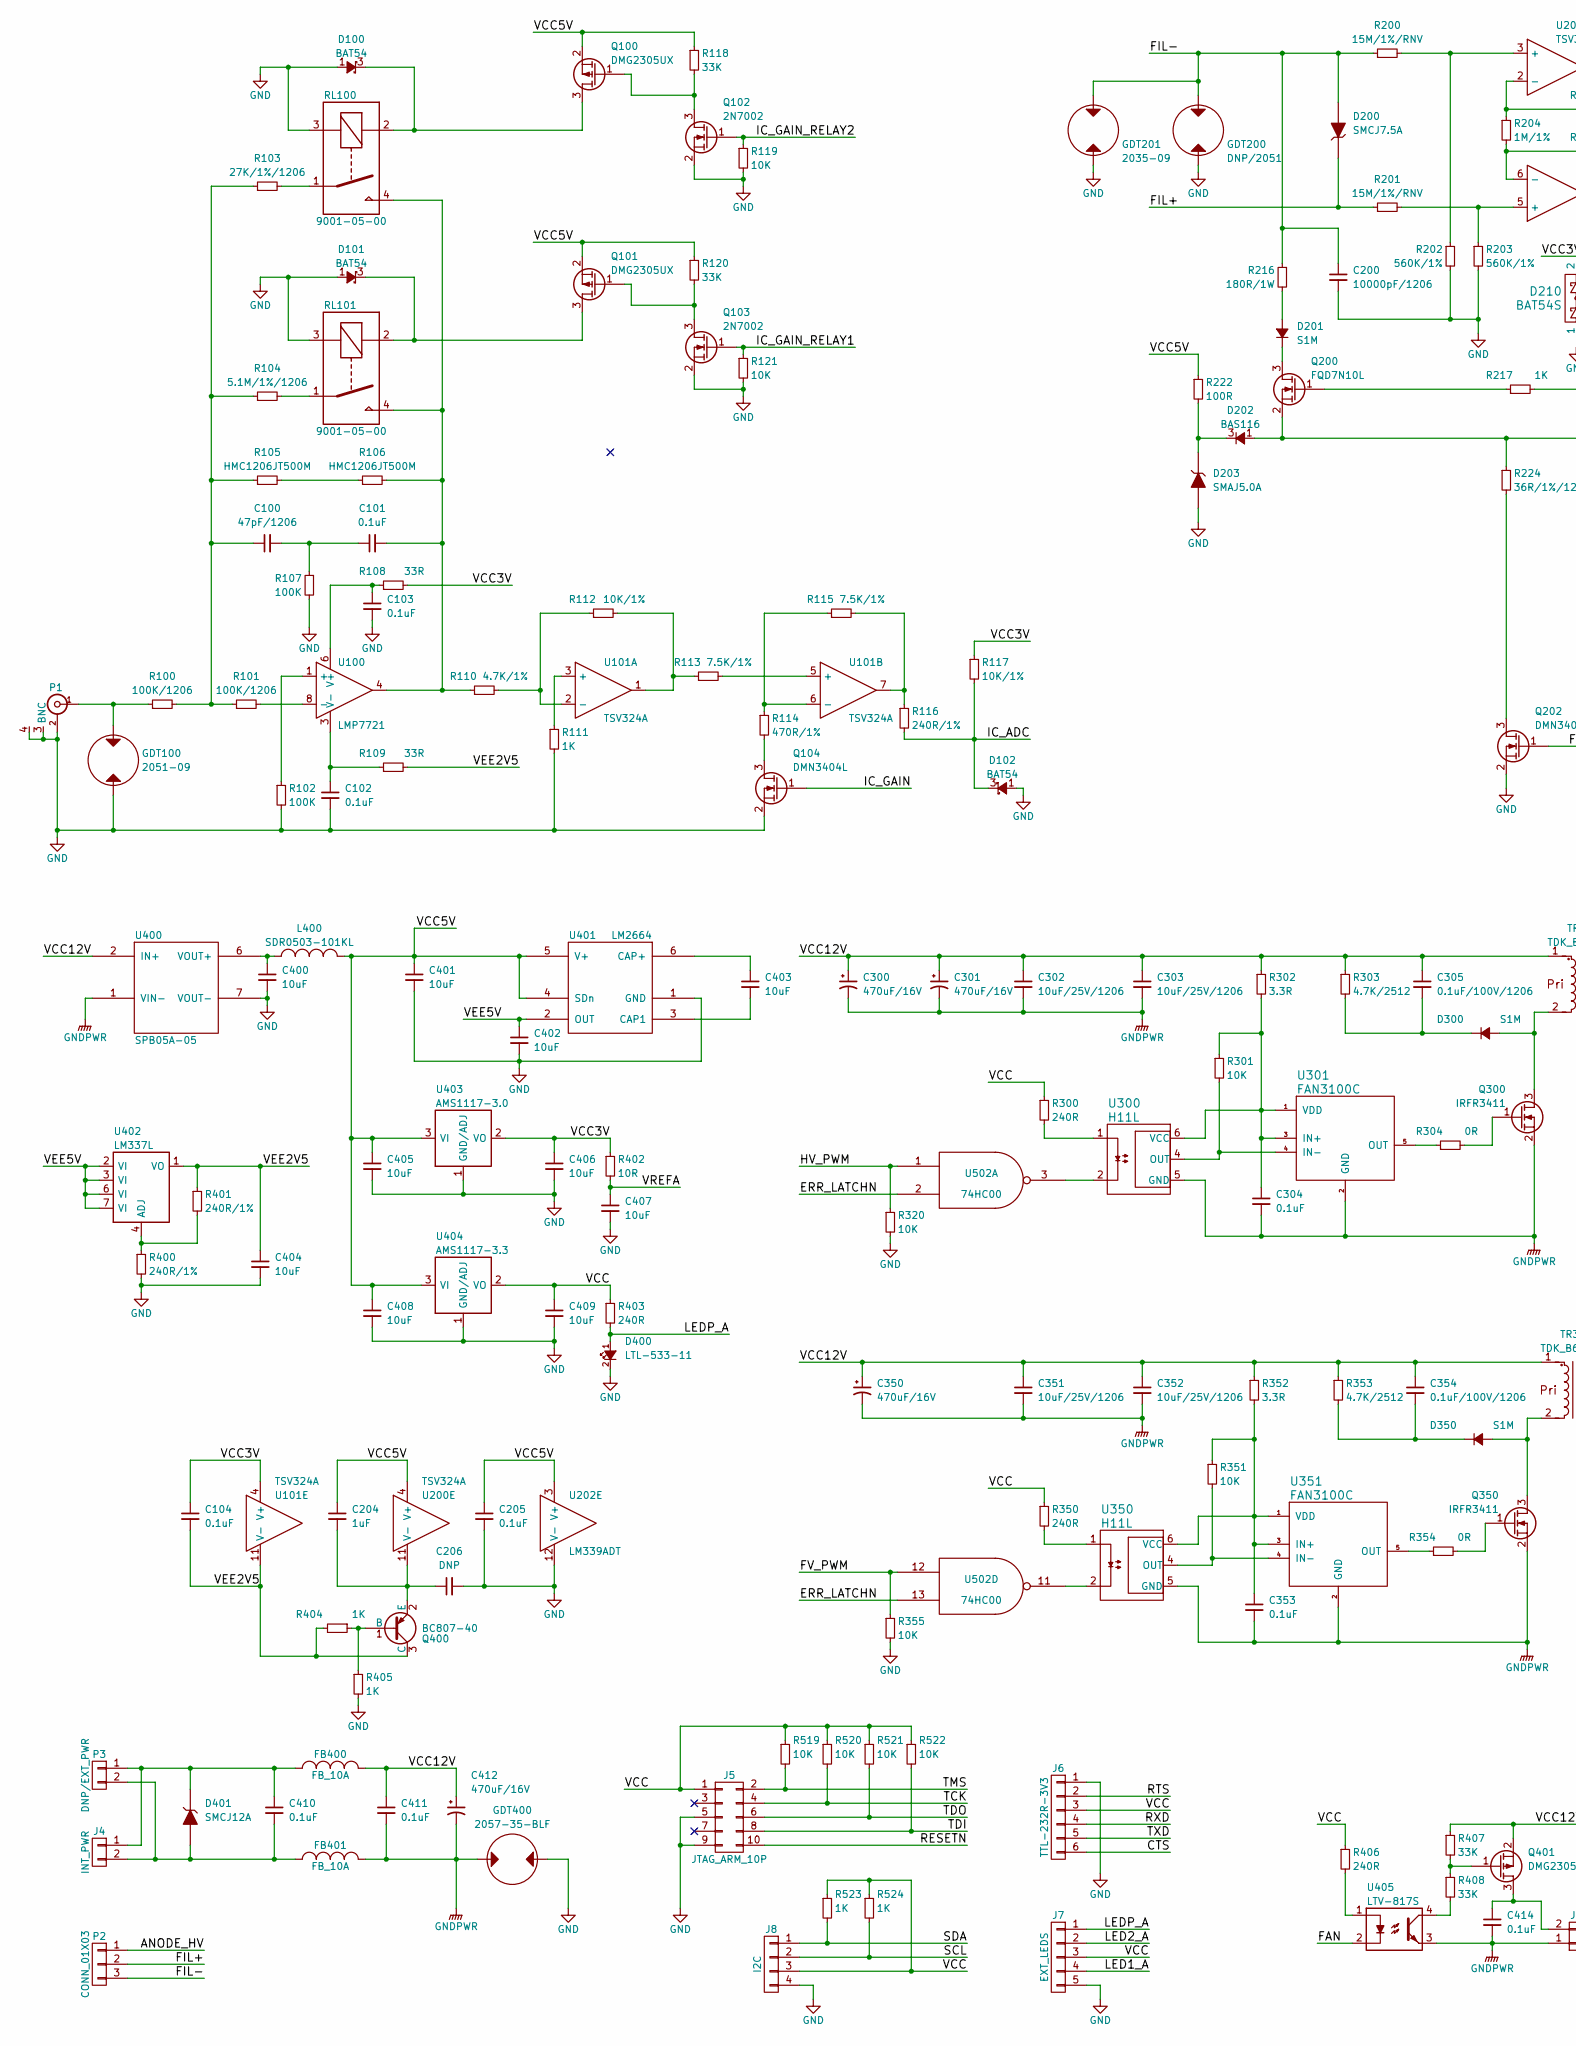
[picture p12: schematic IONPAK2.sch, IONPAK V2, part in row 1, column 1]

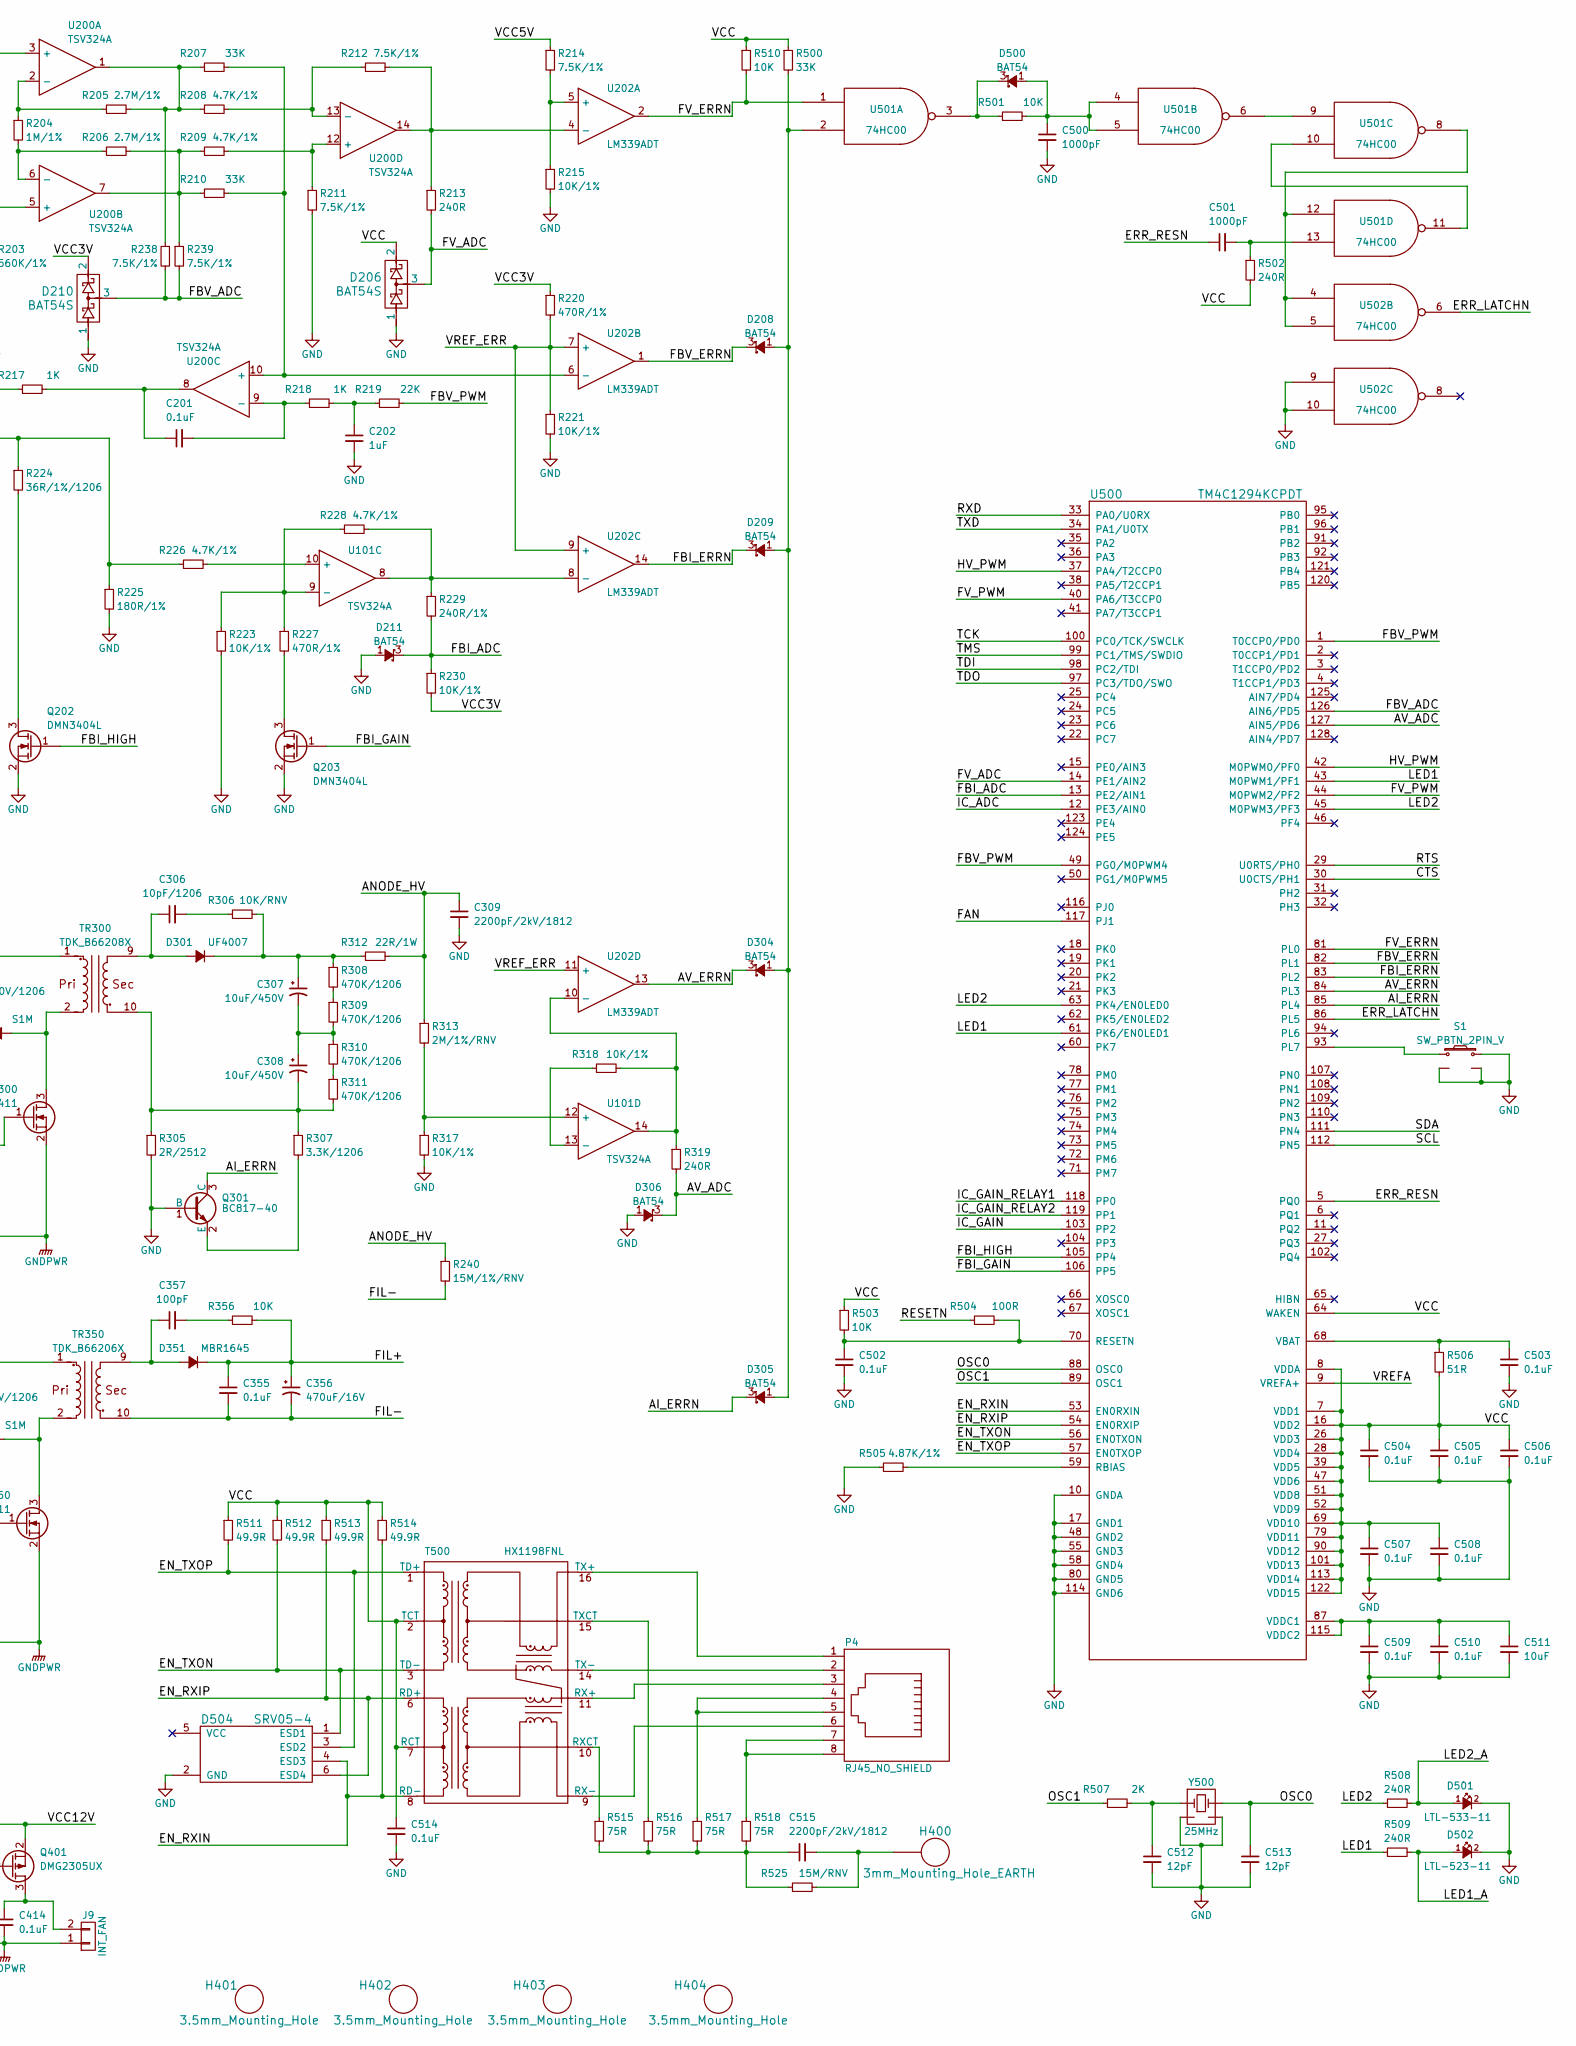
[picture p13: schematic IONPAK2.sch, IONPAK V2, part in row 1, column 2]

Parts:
C100: 47pF/1206; C_1206_ns; MPN 12062A101JAT2A
C101, C102, C103, C104, C201, C205, C304, C353, C355, C410, C411, C414, C502, C503, C504, C505, C506, C507, C508, C509, C510, C514: 0.1uF; C_0603; MPN GRM188R71C104JA01D
C200: 10000pF/1206; C_1206; MPN GRM31BR72J103KW01L
C202, C204: 1uF; C_0603; MPN GRM188R60J105KA01J
C206: DNP; C_0603
C300, C301, C350, C356, C412: 470uF/16V; C_Radial_D13_L21_P5; MPN ECA-1CM471
C302, C303, C351, C352: 10uF/25V/1206; C_1206; MPN CL31A106KAHNNNE
C305, C354: 0.1uF/100V/1206; C_1206; MPN GRJ319R72A104KE11L
C306: 10pF/1206; C_1206; MPN CL31C100JIFNNNE
C307, C308: 10uF/450V; C_Radial_D14_L25_P5; MPN UVR2W100MHD1TO
C309, C515: 2200pF/2kV/1812; C_1812; MPN C1812C222KGRACTU
C357: 100pF; C_0603; MPN GRM0335C1E101JA01D
C400, C401, C402, C403, C404, C405, C406, C407, C408, C409, C511: 10uF; C_0603; MPN GRM188R60J106KE47D
C500, C501: 1000pF; C_0603; MPN GRM033R71C102KA01D
C512, C513: 12pF; C_0603; MPN GRM0335C1E120JA01D
D100, D101, D102, D208, D209, D211, D304, D305, D306, D500: BAT54; SOT-23; MPN BAT54SLT1G
D200: SMCJ7.5A; DO-214AB; MPN SMCJ7.5A-13-F
D201, D300, D350: S1M; DO-214AC; MPN S1MTR
D202: BAS116; SOT-23; MPN BAS116-7-F
D203: SMAJ5.0A; DO-214AC; MPN SMAJ5.0A
D206, D210: BAT54S; SOT-23; MPN BAT54SLT1G
D301: UF4007; Diode_DO-41_SOD81_Horizontal_RM10; MPN UF4007TA
D351: MBR1645; TO220AC; MPN MBR1060
D400, D501: LTL-533-11; LED_D3.0mm_Horizontal_O3.81mm_Z10.0mm; MPN LTL-533-11
D401: SMCJ12A; DO-214AB; MPN SMCJ12A-13-F
D502: LTL-523-11; LED_D3.0mm_Horizontal_O3.81mm_Z10.0mm; MPN LTL-523-11
D504: SRV05-4; SOT-23-6; MPN SRV05-4ATR
FB400, FB401: FB_10A; 28F0121-0SR-10; MPN 28F0121-0SR-10
GDT100: 2051-09; BOURNS-GDT-2051_ns; MPN 2051-09-SM-RPLF
GDT200: DNP/2051; BOURNS-GDT-2051
GDT201: 2035-09; BOURNS-GDT-2035TH; MPN 2035-09-BT1LF
GDT400: 2057-35-BLF; BOURNS-GDT-2035TH; MPN 2057-35-BLF
H400: 3mm_Mounting_Hole_EARTH; 3mm_EARTH
H401, H402, H403, H404: 3.5mm_Mounting_Hole; NPTH_3mm5_ID
J4: INT_PWR; PhoenixContact_MCV-G_02x5.08mm_Vertical; MPN 1836299
J5: JTAG_ARM_10P; Pin_Header_Straight_2x05_Pitch1.27mm; MPN GRPB052VWVN-RC
J6: TTL-232R-3V3; Pin_Header_Straight_1x06_Pitch2.54mm; MPN SWR25X-NRTC-S06-ST-BA
J7: EXT_LEDS; Pin_Header_Straight_1x05_Pitch2.54mm; MPN SWR25X-NRTC-S04-ST-BA
J8: I2C; Pin_Header_Straight_1x04_Pitch2.54mm
J9: INT_FAN; Molex_KK-6410-02_02x2.54mm_Straight; MPN 0022272021
L400: SDR0503-101KL; Choke_SMD_Wuerth-WE-PD2-Typ-MS; MPN SDR0503-101KL
P1: BNC; bnc_90_1-1337543-0_ns; MPN 1-1337543-0
P2: CONN_01X03; PhoenixContact_1786417_03; MPN 1786417
P3: DNP/EXT_PWR; PhoenixContact_MSTBA-G_02x5.08mm_Angled
P4: RJ45_NO_SHIELD; FCI_54601-908WPLF; MPN 54601-908WPLF
Q100, Q101, Q401: DMG2305UX; SOT-23; MPN DMG2305UX-13
Q102, Q103: 2N7002; SOT-23; MPN 2N7002P,215
Q104, Q202, Q203: DMN3404L; SOT-23; MPN DMN3404L-7
Q200: FQD7N10L; DPAK; MPN FQD7N10LTM
Q300, Q350: IRFR3411; DPAK; MPN IRFR3411TRPBF
Q301: BC817-40; SOT-23; MPN BC81740MTF
Q400: BC807-40; SOT-23; MPN BC807-40LT1G
R100, R101: 100K/1206; R_1206_ns; MPN RC1206JR-07100KL
R102, R107: 100K; R_0603; MPN RC0603JR-07100KL
R103: 27K/1%/1206; R_1206_ns; MPN RC1206FR-0727KL
R104: 5.1M/1%/1206; R_1206_ns; MPN RC1206FR-0727KL
R105, R106: HMC1206JT500M; R_1206_ns; MPN HMC1206JT500M
R108, R109: 33R; R_0603; MPN RC0603FR-0733RL
R110, R208, R209, R226, R228: 4.7K/1%; R_0603; MPN RC0603FR-074K7L
R111, R217, R218, R404, R405, R523, R524: 1K; R_0603; MPN RC0603FR-071KL
R112, R117, R215, R221, R223, R230, R317, R318: 10K/1%; R_0603; MPN RC0603FR-0710KL
R113, R115, R211, R212, R214, R238, R239: 7.5K/1%; R_0603; MPN RC0603FR-077K5L
R114, R220, R227: 470R/1%; R_0603; MPN RC0603FR-07470RL
R116, R229, R400, R401: 240R/1%; R_0603; MPN RC0603FR-07240RL
R118, R120, R207, R210, R407, R408, R500: 33K; R_0603; MPN RC0603FR-0733KL
R119, R121, R301, R320, R351, R355, R356, R501, R503, R510, R519, R520, R521, R522: 10K; R_0603; MPN RC0603FR-0710KL
R200, R201, R240: 15M/1%/RNV; R_Axial_DIN0207_L6.3mm_D2.5mm_P10.16mm_Horizontal; MPN RNV14FAL15M0
R202, R203: 560K/1%; R_0603; MPN RC0603FR-07560KL
R204: 1M/1%; R_0603; MPN RC0603FR-071ML
R205, R206: 2.7M/1%; R_0603; MPN RC0603FR-072M7L
R213, R300, R319, R350, R403, R406, R502, R508, R509: 240R; R_0603; MPN RC0603FR-07240RL
R216: 180R/1W; R_Axial_DIN0414_L11.9mm_D4.5mm_P15.24mm_Horizontal; MPN KNP100JR-73-180R
R219: 22K; R_0603; MPN RC0603FR-0722KL
R222, R504: 100R; R_0603; MPN RC0603JR-07100RL
R224: 36R/1%/1206; R_1206; MPN RC1206FR-0736RL
R225: 180R/1%; R_0603; MPN RC0603FR-07180RL
R302, R352: 3.3R; R_0603; MPN RC0603FR-073R3L
R303, R353: 4.7K/2512; R_2512; MPN RC2512JK-074K7L
R304, R354: 0R; R_0603; MPN RC0603JR-070RL
R305: 2R/2512; R_2512; MPN RMCF2512JT2R00
R306: 10K/RNV; R_Axial_DIN0207_L6.3mm_D2.5mm_P10.16mm_Horizontal; MPN RNF14FTD10K0
R307: 3.3K/1206; R_1206; MPN RC1206JR-073K3L
R308, R309, R310, R311: 470K/1206; R_1206; MPN RC1206JR-07470KL
R312: 22R/1W; R_Axial_DIN0414_L11.9mm_D4.5mm_P15.24mm_Horizontal; MPN KNP100JR-73-22R
R313: 2M/1%/RNV; R_Axial_DIN0207_L6.3mm_D2.5mm_P10.16mm_Horizontal; MPN RNV14FAL2M00
R402: 10R; R_0603; MPN RC0603JR-0710RL
R505: 4.87K/1%; R_0603; MPN RC0603FR-074K87L
R506: 51R; R_0603; MPN RC0603FR-0751RL
R507: 2K; R_0603; MPN RC0603FR-072KL
R511, R512, R513, R514: 49.9R; R_0603; MPN RC0603FR-0749R9L
R515, R516, R517, R518: 75R; R_0603; MPN 311-75.0HRCT-ND
R525: 15M/RNV; R_Axial_DIN0207_L6.3mm_D2.5mm_P10.16mm_Horizontal; MPN RNV14FAL15M0
RL100, RL101: 9001-05-00; COTO-9001_ns; MPN 9001-05-00
S1: SW_PBTN_2PIN_V; SW_Tactile_SKHH_Angled_v; MPN 1825027-8
T500: HX1198FNL; H2019FNL; MPN HX1198FNL
TR300: TDK_B66208X; MPN TranformerFl
TR350: TDK_B66206X; MPN TransformerHV
U100: LMP7721; SOIC-8-N_ns; MPN LMP7721MA/NOPB
U101, U200: TSV324A; SOIC-14_N; MPN TSV324IDT
U202: LM339ADT; SOIC-14_N; MPN LM339ADT
U300, U350: H11L; 6-SMD; MPN H11L1S(TA)
U301, U351: FAN3100C; SOT-23-5; MPN FAN3100CSX
U400: SPB05A-05; SPB05A; MPN SPB05A-05
U401: LM2664; SOT-23-6; MPN LM2664M6/NOPB
U402: LM337L; SOIC-8-N; MPN LM337LMX
U403: AMS1117-3.0; SOT-223; MPN TLV1117LV30DCYR
U404: AMS1117-3.3; SOT-223; MPN AZ1117IH-3.3TRG1
U405: LTV-817S; OPTO-SMD4; MPN LTV-817S-TA1
U500: TM4C1294KCPDT; TQFP-128; MPN TM4C1294KCPDTI3R
U501, U502: 74HC00; SOIC-14_N; MPN 74HC00S14-13
Y500: 25MHz; XTAL3_2X2_5; MPN NX3225GA-25.000M-STD-CRG-2

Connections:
/AI_ERRN: D305.3 (K), Q301.3 (C), U500.85 (PL4)
/ANODE_HV: C309.1, P2.1, R240.1, R312.2, R313.1
/AV_ADC: D306.3 (K), R319.2, U500.127 (AIN5/PD6)
/AV_ERRN: D304.3 (K), U202.13, U500.84 (PL3)
/CTS: J6.6, U500.30 (U0CTS/PH1)
/EN_RXIN: D504.4 (ESD3), R514.2, T500.8 (RD-), U500.53 (EN0RXIN)
/EN_RXIP: D504.6 (ESD4), R513.2, T500.6 (RD+), U500.54 (EN0RXIP)
/EN_TXON: D504.1 (ESD1), R512.2, T500.3 (TD-), U500.56 (EN0TXON)
/EN_TXOP: D504.3 (ESD2), R511.2, T500.1 (TD+), U500.57 (EN0TXOP)
/ERR_LATCHN: U500.86 (PL5), U502.2, U502.6, U502.13
/ERR_RESN: C501.1, U500.5 (PQ0)
/FAN: U405.2, U500.117 (PJ1)
/FBI_ADC: D211.3 (K), R229.2, R230.1, U500.13 (PE2/AIN1)
/FBI_ERRN: D209.3 (K), U202.14, U500.83 (PL2)
/FBI_GAIN: Q203.1 (G), U500.106 (PP5)
/FBI_HIGH: Q202.1 (G), U500.105 (PP4)
/FBV_ADC: D210.3, R238.2, R239.2, U500.126 (AIN6/PD5)
/FBV_ERRN: D208.3 (K), U202.1, U500.82 (PL1)
/FBV_PWM: R219.2, U500.1 (T0CCP0/PD0), U500.49 (PG0/M0PWM4)
/FIL+: C355.1, C356.1, D200.1 (K), D351.1 (K), P2.2, R201.1, R356.2
/FIL-: C200.1, C355.2, C356.2, D200.2 (A), GDT200.1, GDT201.1, P2.3, R200.1, R216.1, R240.2, TR350.10
/FV_ADC: D206.3, R213.2, U500.14 (PE1/AIN2)
/FV_ERRN: R510.2, U202.2, U500.81 (PL0), U501.1
/FV_PWM: R355.1, U500.40 (PA6/T3CCP0), U500.44 (M0PWM2/PF2), U502.12
/HV_PWM: R320.1, U500.37 (PA4/T2CCP0), U500.42 (M0PWM0/PF0), U502.1
/IC_ADC: D102.3 (K), R116.2, R117.2, U500.12 (PE3/AIN0)
/IC_GAIN: Q104.1 (G), U500.103 (PP2)
/IC_GAIN_RELAY1: Q103.1 (G), R121.1, U500.118 (PP0)
/IC_GAIN_RELAY2: Q102.1 (G), R119.1, U500.119 (PP1)
/LED1: R509.1, U500.43 (M0PWM1/PF1), U500.61 (PK6/EN0LED1)
/LED1_A: D502.1 (A), J7.4, R509.2
/LED2: R508.1, U500.45 (M0PWM3/PF3), U500.63 (PK4/EN0LED0)
/LED2_A: D501.1 (A), J7.2, R508.2
/LEDP_A: D400.1 (A), J7.1, R403.2
/OSC0: C513.1, U500.88 (OSC0), Y500.3
/OSC1: R507.1, U500.89 (OSC1)
/RESETN: J5.10, R504.1
/RTS: J6.2, U500.29 (U0RTS/PH0)
/RXD: J6.4, U500.33 (PA0/U0RX)
/SCL: J8.2, R524.2, U500.112 (PN5)
/SDA: J8.1, R523.2, U500.111 (PN4)
/TCK: J5.4, R520.2, U500.100 (PC0/TCK/SWCLK)
/TDI: J5.8, R522.2, U500.98 (PC2/TDI)
/TDO: J5.6, R521.2, U500.97 (PC3/TDO/SWO)
/TMS: J5.2, R519.2, U500.99 (PC1/TMS/SWDIO)
/TXD: J6.5, U500.34 (PA1/U0TX)
/VCC3V: C104.1, C406.1, D210.2, R108.2, R117.1, R220.1, R230.2, R402.1, U101.4 (V+), U403.2 (VO)
/VCC5V: C204.1, C205.1, C401.1, C405.1, C408.1, L400.2, Q100.2 (S), Q101.2 (S), R118.1, R120.1, R214.1, R222.1, U200.4 (V+), U202.3 (V+), U401.4 (SDn), U401.5 (V+), U403.3 (VI), U404.3 (VI)
/VCC12V: C300.1, C301.1, C302.1, C303.1, C305.1, C350.1, C351.1, C352.1, C354.1, C411.1, C412.1, FB400.2, Q401.2 (S), R302.1, R303.1, R352.1, R353.1, R407.1, TR300.1, TR350.1, U400.2 (IN+)
/VEE2V5: C104.2, C404.1, Q400.3 (C), R109.2, R401.1, R404.2, U101.11 (V-), U402.1 (VO)
/VEE5V: C402.1, U401.2 (OUT), U402.2 (VI), U402.3 (VI), U402.6 (VI), U402.7 (VI)
/VREFA: C407.1, R402.2, U500.9 (VREFA+)
/VREF_ERR: R220.2, R221.1, U202.7 (+), U202.9 (+), U202.11 (+)
GND: C102.2, C103.2, C200.2, C202.2, C205.2, C206.2, C309.2, C400.2, C401.2, C402.2, C404.2, C405.2, C406.2, C407.2, C408.2, C409.2, C500.2, C502.2, C503.2, C504.2, C505.2, C506.2, C507.2, C508.2, C509.2, C510.2, C511.2, C512.2, C513.2, C514.2, D100.1 (A), D101.1 (A), D102.1 (A), D203.2 (A), D206.1, D210.1, D211.1 (A), D306.1 (A), D400.2 (K), D501.2 (K), D502.2 (K), D504.2 (GND), GDT100.2, GDT200.2, GDT201.2, GDT400.1, J5.5, J5.9, J6.1, J7.5, J8.4, P1.2 (Ext), P1.3 (M1), P1.4 (M2), Q102.2 (S), Q103.2 (S), Q104.2 (S), Q202.2 (S), Q203.2 (S), Q301.1 (B), R102.2, R107.2, R111.2, R119.2, R121.2, R202.2, R203.2, R211.2, R215.2, R221.2, R223.2, R225.2, R305.2, R317.2, R320.2, R355.2, R400.2, R405.2, R505.1, RL100.3, RL101.3, S1.2, S1.3 (GND), S1.4 (GND), U100.2 (GND), U100.7 (GND), U202.12 (V-), U400.7 (VOUT-), U401.1 (GND), U403.1 (GND/ADJ), U404.1 (GND/ADJ), U500.10 (GNDA), U500.17 (GND1), U500.48 (GND2), U500.55 (GND3), U500.58 (GND4), U500.80 (GND5), U500.114 (GND6), U501.7 (GND), U502.7 (GND), U502.9, U502.10, Y500.2 (GND), Y500.4 (GND)
GNDPWR: C300.2, C301.2, C302.2, C303.2, C304.2, C350.2, C351.2, C352.2, C353.2, C411.2, C412.2, C414.2, FB401.2, GDT400.2, J9.1, Q300.2 (S), Q350.2 (S), U300.5 (GND), U301.2 (GND), U350.5 (GND), U351.2 (GND), U400.1 (VIN-), U405.3
unnamed: C100.1, R100.2, R101.1, R103.1, R104.1, R105.1
unnamed: C100.2, C101.1, R107.1
unnamed: C101.2, R106.2, R110.1, RL100.4, RL101.4, U100.4
unnamed: C102.1, R109.1, U100.3 (V-)
unnamed: C103.1, R108.1, U100.6 (V+)
unnamed: C201.1, R217.2, U200.8
unnamed: C201.2, R218.1, U200.9 (-)
unnamed: C202.1, R218.2, R219.1
unnamed: C204.2, C206.1, Q400.2 (E), U200.11 (V-)
unnamed: C304.1, R301.1, R302.2, U300.6 (VCC), U301.1 (VDD), U301.3 (IN+)
unnamed: C305.2, D300.1 (K), R303.2
unnamed: C306.1, D301.2 (A), TR300.9
unnamed: C306.2, R306.1
unnamed: C307.1, D301.1 (K), R306.2, R308.1, R312.1
unnamed: C307.2, C308.1, R309.2, R310.1
unnamed: C308.2, R305.1, R307.1, R311.2, TR300.10
unnamed: C353.1, R351.1, R352.2, U350.6 (VCC), U351.1 (VDD), U351.3 (IN+)
unnamed: C354.2, D350.1 (K), R353.2
unnamed: C357.1, D351.2 (A), TR350.9
unnamed: C357.2, R356.1
unnamed: C400.1, L400.1, U400.6 (VOUT+)
unnamed: C403.1, U401.6 (CAP+)
unnamed: C403.2, U401.3 (CAP1)
unnamed: C410.1, D401.1 (K), FB400.1, J4.1, P3.1
unnamed: C410.2, D401.2 (A), FB401.1, J4.2, P3.2
unnamed: C414.1, J9.2, Q401.3 (D)
unnamed: C500.1, D500.1 (A), R501.2, U501.4, U501.5
unnamed: C501.2, R502.1, U501.13
unnamed: C502.1, R503.2, R504.2, U500.70 (RESETN)
unnamed: C503.1, R506.1, U500.68 (VBAT)
unnamed: C509.1, C510.1, C511.1, U500.87 (VDDC1), U500.115 (VDDC2)
unnamed: C512.1, R507.2, Y500.1
unnamed: C515.1, R515.2, R516.2, R517.2, R518.2, R525.1
unnamed: C515.2, H400.1, R525.2
unnamed: D100.3 (K), Q100.3 (D), RL100.2
unnamed: D101.3 (K), Q101.3 (D), RL101.2
unnamed: D201.1 (K), Q200.3 (D)
unnamed: D201.2 (A), R216.2
unnamed: D202.1 (A), Q200.2 (S), R224.1, R225.1, R226.1
unnamed: D202.3 (K), D203.1 (K), R222.2
unnamed: D208.1 (A), D209.1 (A), D304.1 (A), D305.1 (A), R500.2, U501.2
unnamed: D300.2 (A), Q300.3 (D), TR300.2
unnamed: D350.2 (A), Q350.3 (D), TR350.2
unnamed: D500.3 (K), R501.1, U501.3
unnamed: GDT100.1, P1.1 (In), R100.1
unnamed: P4.1, T500.16 (TX+)
unnamed: P4.2, T500.14 (TX-)
unnamed: P4.3, T500.11 (RX+)
unnamed: P4.4, P4.5, R517.1
unnamed: P4.6, T500.9 (RX-)
unnamed: P4.7, P4.8, R518.1
unnamed: Q100.1 (G), Q102.3 (D), R118.2
unnamed: Q101.1 (G), Q103.3 (D), R120.2
unnamed: Q104.3 (D), R114.2
unnamed: Q200.1 (G), R217.1
unnamed: Q202.3 (D), R224.2
unnamed: Q203.3 (D), R227.2
unnamed: Q300.1 (G), R304.2
unnamed: Q301.2 (E), R307.2
unnamed: Q350.1 (G), R354.2
unnamed: Q400.1 (B), R404.1, R405.1
unnamed: Q401.1 (G), R407.2, R408.1
unnamed: R101.2, U100.8 (-)
unnamed: R102.1, U100.1 (+)
unnamed: R103.2, RL100.1
unnamed: R104.2, RL101.1
unnamed: R105.2, R106.1
unnamed: R110.2, R112.1, U101.2 (-)
unnamed: R111.1, U101.3 (+)
unnamed: R112.2, R113.1, U101.1
unnamed: R113.2, U101.5 (+)
unnamed: R114.1, R115.1, U101.6 (-)
unnamed: R115.2, R116.1, U101.7
unnamed: R200.2, R202.1, U200.3 (+)
unnamed: R201.2, R203.1, U200.5 (+)
unnamed: R204.1, R205.1, U200.2 (-)
unnamed: R204.2, R206.1, U200.6 (-)
unnamed: R205.2, R207.1, R208.1, R238.1, U200.1
unnamed: R206.2, R209.1, R210.1, R239.1, U200.7
unnamed: R207.2, R210.2, U200.10 (+), U202.6 (-)
unnamed: R208.2, R212.1, U200.13 (-)
unnamed: R209.2, R211.1, U200.12 (+)
unnamed: R212.2, R213.1, U200.14, U202.4 (-)
unnamed: R214.2, R215.1, U202.5 (+)
unnamed: R223.1, R227.1, R228.1, U101.9 (-)
unnamed: R226.2, U101.10 (+)
unnamed: R228.2, R229.1, U101.8, U202.8 (-)
unnamed: R300.2, U300.1
unnamed: R301.2, U300.4 (OUT), U301.4 (IN-)
unnamed: R304.1, U301.5 (OUT)
unnamed: R308.2, R309.1
unnamed: R310.2, R311.1
unnamed: R313.2, R317.1, U101.12 (+)
unnamed: R318.1, U101.13 (-)
unnamed: R318.2, R319.1, U101.14, U202.10 (-)
unnamed: R350.2, U350.1
unnamed: R351.2, U350.4 (OUT), U351.4 (IN-)
unnamed: R354.1, U351.5 (OUT)
unnamed: R400.1, R401.2, U402.4 (ADJ)
unnamed: R406.2, U405.1
unnamed: R408.2, U405.4
unnamed: R505.2, U500.59 (RBIAS)
unnamed: R515.1, T500.10 (RXCT)
unnamed: R516.1, T500.15 (TXCT)
unnamed: S1.1, U500.93 (PL7)
unnamed: U300.2, U502.3
unnamed: U350.2, U502.11
unnamed: U501.6, U501.9
unnamed: U501.10, U501.11
unnamed: U501.8, U501.12, U502.4, U502.5
VCC: C409.1, C504.1, C505.1, C506.1, C507.1, C508.1, C514.1, D206.2, J5.1, J6.3, J7.3, J8.3, R300.1, R350.1, R403.1, R406.1, R500.1, R502.2, R503.1, R506.2, R510.1, R511.1, R512.1, R513.1, R514.1, R519.1, R520.1, R521.1, R522.1, R523.1, R524.1, T500.2 (TCT), T500.7 (RCT), U404.2 (VO), U500.7 (VDD1), U500.8 (VDDA), U500.16 (VDD2), U500.26 (VDD3), U500.28 (VDD4), U500.39 (VDD5), U500.47 (VDD6), U500.51 (VDD8), U500.52 (VDD9), U500.64 (WAKEN), U500.69 (VDD10), U500.79 (VDD11), U500.90 (VDD12), U500.101 (VDD13), U500.113 (VDD14), U500.122 (VDD15), U501.14 (VCC), U502.14 (VCC)

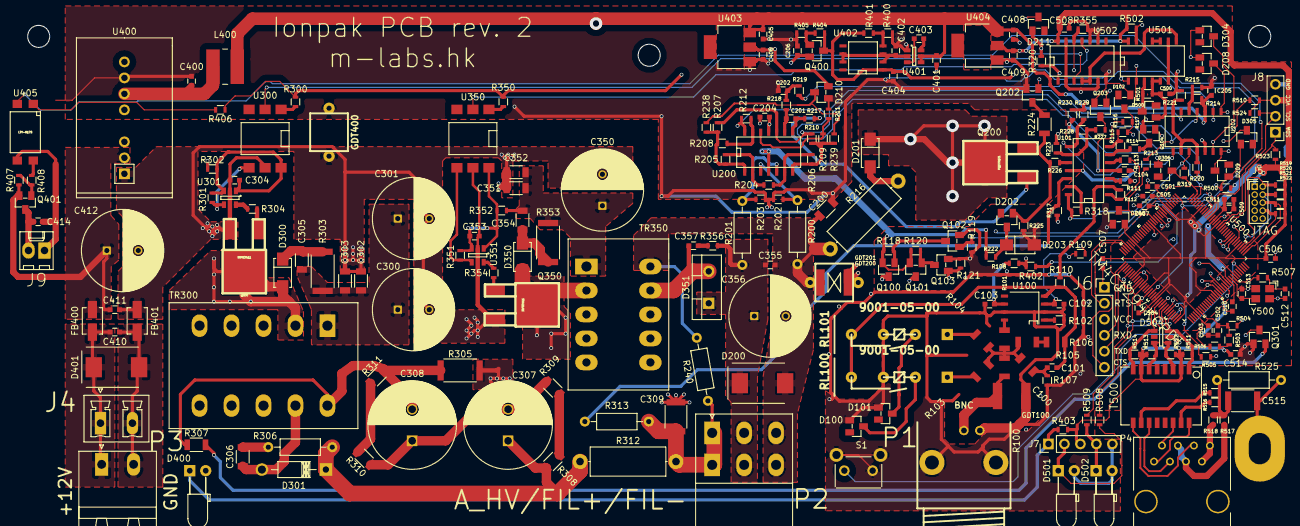
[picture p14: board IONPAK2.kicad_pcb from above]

Board: 4 copper layers, 259 parts (0 on the bottom side), 166 nets.

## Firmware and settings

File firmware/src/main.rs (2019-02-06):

#![feature(const_fn)]
#![no_std]
#![no_main]

extern crate libm;
extern crate cortex_m;
#[macro_use]
extern crate cortex_m_rt;
#[macro_use(interrupt)]
extern crate tm4c129x;
extern crate smoltcp;
extern crate crc;

use core::cell::{Cell, RefCell};
use core::fmt;
use cortex_m::interrupt::Mutex;
use smoltcp::time::Instant;
use smoltcp::wire::EthernetAddress;
use smoltcp::iface::{NeighborCache, EthernetInterfaceBuilder};
use smoltcp::socket::{SocketSet, TcpSocket, TcpSocketBuffer};

#[macro_export]
macro_rules! print {
    ($($arg:tt)*) => ({
        use core::fmt::Write;
        write!($crate::UART0, $($arg)*).unwrap()
    })
}

#[macro_export]
macro_rules! println {
    ($fmt:expr) => (print!(concat!($fmt, "\n")));
    ($fmt:expr, $($arg:tt)*) => (print!(concat!($fmt, "\n"), $($arg)*));
}

#[no_mangle] // https://github.com/rust-lang/rust/issues/{38281,51647}
#[panic_handler]
pub fn panic_fmt(info: &core::panic::PanicInfo) -> ! {
    println!("{}", info);
    loop {}
}

#[macro_use]
mod board;
mod eeprom;
mod config;
mod ethmac;
mod pid;
mod loop_anode;
mod loop_cathode;
mod electrometer;
mod http;
mod pages;

static ADC_IRQ_COUNT: Mutex<Cell<u64>> = Mutex::new(Cell::new(0));

fn get_time_ms() -> u64 {
    let adc_irq_count = cortex_m::interrupt::free(|cs| {
        ADC_IRQ_COUNT.borrow(cs).get()
    });
    adc_irq_count*24/125
}

static LOOP_ANODE: Mutex<RefCell<loop_anode::Controller>> = Mutex::new(RefCell::new(
    loop_anode::Controller::new()));

static LOOP_CATHODE: Mutex<RefCell<loop_cathode::Controller>> = Mutex::new(RefCell::new(
    loop_cathode::Controller::new()));

static ELECTROMETER: Mutex<RefCell<electrometer::Electrometer>> = Mutex::new(RefCell::new(
    electrometer::Electrometer::new()));


pub struct UART0;

impl fmt::Write for UART0 {
    fn write_str(&mut self, s: &str) -> Result<(), fmt::Error> {
        let uart_0 = unsafe { &*tm4c129x::UART0::ptr() };
        for c in s.bytes() {
            while uart_0.fr.read().txff().bit() {}
            uart_0.dr.write(|w| w.data().bits(c))
        }
        Ok(())
    }
}

const TCP_RX_BUFFER_SIZE: usize = 256;
const TCP_TX_BUFFER_SIZE: usize = 8192;


macro_rules! create_socket_storage {
    ($rx_storage:ident, $tx_storage:ident) => (
        let mut $rx_storage = [0; TCP_RX_BUFFER_SIZE];
        let mut $tx_storage = [0; TCP_TX_BUFFER_SIZE];
    )
}

macro_rules! create_socket {
    ($set:ident, $rx_storage:ident, $tx_storage:ident, $target:ident) => (
        let tcp_rx_buffer = TcpSocketBuffer::new(&mut $rx_storage[..]);
        let tcp_tx_buffer = TcpSocketBuffer::new(&mut $tx_storage[..]);
        let tcp_socket = TcpSocket::new(tcp_rx_buffer, tcp_tx_buffer);
        let $target = $set.add(tcp_socket);
    )
}

#[entry]
fn main() -> ! {
    board::init();
    let button_pressed = board::get_button();

    let mut config = config::Config::new();
    eeprom::init();
    if button_pressed {
        config.save();
    } else {
        config.load();
    }

    cortex_m::interrupt::free(|cs| {
        let mut loop_anode = LOOP_ANODE.borrow(cs).borrow_mut();
        let mut loop_cathode = LOOP_CATHODE.borrow(cs).borrow_mut();

        // ZJ-10
        let anode = 165.0;
        let cathode_bias = 50.0;
        let emission = 0.5e-3;

        // ZJ-27
        /*let anode = 225.0;
        let cathode_bias = 25.0;
        let emission = 1.0e-3;*/

        // ZJ-12
        /*let anode = 200.0;
        let cathode_bias = 50.0;
        let emission = 4.0e-3;*/

        // G8130
        /*let anode = 180.0;
        let cathode_bias = 30.0;
        let emission = 4.0e-3;*/

        loop_anode.set_target(anode);
        loop_cathode.set_emission_target(emission);
        loop_cathode.set_bias_target(cathode_bias);
    });

    println!(r#"
  _                         _
 (_)                       | |
  _  ___  _ __  _ __   __ _| |
 | |/ _ \| '_ \| '_ \ / _` | |/ /
 | | (_) | | | | |_) | (_| |   <
 |_|\___/|_| |_| .__/ \__,_|_|\_\
               | |
               |_|
"#);

    let mut hardware_addr = EthernetAddress(board::get_mac_address());
    if hardware_addr.is_multicast() {
        println!("programmed MAC address is invalid, using default");
        hardware_addr = EthernetAddress([0x10, 0xE2, 0xD5, 0x00, 0x03, 0x00]);
    }
    let mut ip_addrs = [config.ip];
    println!("MAC {} IP {}", hardware_addr, ip_addrs[0]);
    let mut neighbor_cache_storage = [None; 8];
    let neighbor_cache = NeighborCache::new(&mut neighbor_cache_storage[..]);
    let mut device = ethmac::Device::new();
    unsafe { device.init(hardware_addr) };
    let mut iface = EthernetInterfaceBuilder::new(&mut device)
                .ethernet_addr(hardware_addr)
                .neighbor_cache(neighbor_cache)
                .ip_addrs(&mut ip_addrs[..])
                .finalize();

    create_socket_storage!(tcp_rx_storage0, tcp_tx_storage0);
    create_socket_storage!(tcp_rx_storage1, tcp_tx_storage1);
    create_socket_storage!(tcp_rx_storage2, tcp_tx_storage2);
    create_socket_storage!(tcp_rx_storage3, tcp_tx_storage3);
    create_socket_storage!(tcp_rx_storage4, tcp_tx_storage4);
    create_socket_storage!(tcp_rx_storage5, tcp_tx_storage5);
    create_socket_storage!(tcp_rx_storage6, tcp_tx_storage6);
    create_socket_storage!(tcp_rx_storage7, tcp_tx_storage7);

    let mut socket_set_entries: [_; 8] = Default::default();
    let mut sockets = SocketSet::new(&mut socket_set_entries[..]);

    create_socket!(sockets, tcp_rx_storage0, tcp_tx_storage0, tcp_handle0);
    create_socket!(sockets, tcp_rx_storage1, tcp_tx_storage1, tcp_handle1);
    create_socket!(sockets, tcp_rx_storage2, tcp_tx_storage2, tcp_handle2);
    create_socket!(sockets, tcp_rx_storage3, tcp_tx_storage3, tcp_handle3);
    create_socket!(sockets, tcp_rx_storage4, tcp_tx_storage4, tcp_handle4);
    create_socket!(sockets, tcp_rx_storage5, tcp_tx_storage5, tcp_handle5);
    create_socket!(sockets, tcp_rx_storage6, tcp_tx_storage6, tcp_handle6);
    create_socket!(sockets, tcp_rx_storage7, tcp_tx_storage7, tcp_handle7);

    let mut sessions = [
        (http::Request::new(), tcp_handle0),
        (http::Request::new(), tcp_handle1),
        (http::Request::new(), tcp_handle2),
        (http::Request::new(), tcp_handle3),
        (http::Request::new(), tcp_handle4),
        (http::Request::new(), tcp_handle5),
        (http::Request::new(), tcp_handle6),
        (http::Request::new(), tcp_handle7),
    ];

    board::start_adc();

    let mut fast_blink_count = if button_pressed { 40 } else { 0 };
    let mut next_blink = 0;
    let mut led_state = true;
    let mut latch_reset_time = None;
    loop {
        let time = get_time_ms();

        for &mut(ref mut request, tcp_handle) in sessions.iter_mut() {
            let socket = &mut *sockets.get::<TcpSocket>(tcp_handle);
            if !socket.is_open() {
                socket.listen(80).unwrap()
            }

            if socket.may_recv() {
                match socket.recv(|data| (data.len(), request.input(data))).unwrap() {
                    Ok(true) => {
                        if socket.can_send() {
                            pages::serve(socket, &request, &mut config, &LOOP_ANODE, &LOOP_CATHODE, &ELECTROMETER);
                        }
                        request.reset();
                        socket.close();
                    }
                    Ok(false) => (),
                    Err(err) => {
                        println!("failed HTTP request: {}", err);
                        request.reset();
                        socket.close();
                    }
                }
            } else if socket.may_send() {
                request.reset();
                socket.close();
            }
        }
        match iface.poll(&mut sockets, Instant::from_millis(time as i64)) {
            Ok(_) => (),
            Err(e) => println!("poll error: {}", e)
        }

        if time > next_blink {
            led_state = !led_state;
            if fast_blink_count > 0 {
                fast_blink_count -= 1;
                next_blink = time + 100;
            } else {
                next_blink = time + 500;
            }
            board::set_led(led_state);
        }

        board::process_errors();
        if board::error_latched() {
            match latch_reset_time {
                None => {
                    println!("Protection latched");
                    latch_reset_time = Some(time + 5000);
                }
                Some(t) => if time > t {
                    latch_reset_time = None;
                    cortex_m::interrupt::free(|cs| {
                        // reset PID loops as they have accumulated large errors
                        // while the protection was active, which would cause
                        // unnecessary overshoots.
                        LOOP_ANODE.borrow(cs).borrow_mut().reset();
                        LOOP_CATHODE.borrow(cs).borrow_mut().reset();
                        board::reset_error();
                    });
                    println!("Protection reset");
                }
            }
        }
    }
}

interrupt!(ADC0SS0, adc0_ss0);
fn adc0_ss0() {
    cortex_m::interrupt::free(|cs| {
        let adc0 = unsafe { &*tm4c129x::ADC0::ptr() };
        if adc0.ostat.read().ov0().bit() {
            panic!("ADC FIFO overflowed")
        }
        adc0.isc.write(|w| w.in0().bit(true));

        let ic_sample  = adc0.ssfifo0.read().data().bits();
        let fbi_sample = adc0.ssfifo0.read().data().bits();
        let fv_sample  = adc0.ssfifo0.read().data().bits();
        let fd_sample  = adc0.ssfifo0.read().data().bits();
        let av_sample  = adc0.ssfifo0.read().data().bits();
        let fbv_sample = adc0.ssfifo0.read().data().bits();

        let mut loop_anode = LOOP_ANODE.borrow(cs).borrow_mut();
        let mut loop_cathode = LOOP_CATHODE.borrow(cs).borrow_mut();
        let mut electrometer = ELECTROMETER.borrow(cs).borrow_mut();
        loop_anode.adc_input(av_sample);
        loop_cathode.adc_input(fbi_sample, fd_sample, fv_sample, fbv_sample);
        electrometer.adc_input(ic_sample);

        let adc_irq_count = ADC_IRQ_COUNT.borrow(cs);
        adc_irq_count.set(adc_irq_count.get() + 1);
    });
}

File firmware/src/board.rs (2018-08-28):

use cortex_m;
use tm4c129x;


const LED1: u8 = 0x10; // PK4
const LED2: u8 = 0x40; // PK6

const HV_PWM: u8 = 0x01;  // PF0
const FV_PWM: u8 = 0x04;  // PF2
const FBV_PWM: u8 = 0x01; // PD5

const FD_ADC: u8 = 0x01;  // PE0
const FV_ADC: u8 = 0x02;  // PE1
const FBI_ADC: u8 = 0x04; // PE2
const IC_ADC: u8 = 0x08;  // PE3
const FBV_ADC: u8 = 0x20; // PD5
const AV_ADC: u8 = 0x40;  // PD6

const FV_ERRN: u8 = 0x01;    // PL0
const FBV_ERRN: u8 = 0x02;   // PL1
const FBI_ERRN: u8 = 0x04;   // PL2
const AV_ERRN: u8 = 0x08;    // PL3
const AI_ERRN: u8 = 0x10;    // PL4
const ERR_LATCHN: u8 = 0x20; // PL5
const BTNN: u8 = 0x80;       // PL7
const ERR_RESN: u8 = 0x01;   // PQ0

const PWM_LOAD: u16 = (/*pwmclk*/120_000_000u32 / /*freq*/100_000) as u16;
const UART_DIV: u32 = (((/*sysclk*/120_000_000 * 8) / /*baud*/115200) + 1) / 2;


pub const AV_ADC_GAIN: f32 = 6.792703150912105;
pub const FV_ADC_GAIN: f32 = 501.83449105726623;
pub const FBI_ADC_GAIN: f32 = 1333.3333333333333;
pub const FBI_ADC_OFFSET: f32 = 96.0;
pub const FD_ADC_GAIN: f32 = 3111.1111111111104;
pub const FD_ADC_OFFSET: f32 = 96.0;
pub const FBV_ADC_GAIN: f32 = 49.13796058269066;
pub const FBV_PWM_GAIN: f32 = 0.07641071428571428;
pub const IC_ADC_GAIN_LOW: f32 = 1333333333333.3333;
pub const IC_ADC_GAIN_MED: f32 = 13201320132.0132;
pub const IC_ADC_GAIN_HIGH: f32 = 133320001.3332;
pub const IC_ADC_OFFSET: f32 = 96.0;

pub const FBI_R223: f32 = 200.0;
pub const FBI_R224: f32 = 39.0;
pub const FBI_R225: f32 = 22000.0;


pub fn set_led(state: bool) {
    cortex_m::interrupt::free(|_cs| {
        let gpio_k = unsafe { &*tm4c129x::GPIO_PORTK::ptr() };
        if state {
            gpio_k.data.modify(|r, w| w.data().bits(r.data().bits() | LED2))
        } else {
            gpio_k.data.modify(|r, w| w.data().bits(r.data().bits() & !LED2))
        }
    });
}

pub fn get_button() -> bool {
    let gpio_dat = cortex_m::interrupt::free(|_cs| {
        let gpio_l = unsafe { &*tm4c129x::GPIO_PORTL::ptr() };
        gpio_l.data.read().bits() as u8
    });
    gpio_dat & BTNN == 0
}

pub fn set_hv_pwm(duty: u16) {
    cortex_m::interrupt::free(|_cs| {
        let pwm0 = unsafe { &*tm4c129x::PWM0::ptr() };
        pwm0._0_cmpa.write(|w| w.compa().bits(duty));
    });
}

pub fn set_fv_pwm(duty: u16) {
    cortex_m::interrupt::free(|_cs| {
        let pwm0 = unsafe { &*tm4c129x::PWM0::ptr() };
        pwm0._1_cmpa.write(|w| w.compa().bits(duty));
    });
}

pub fn set_fbv_pwm(duty: u16) {
    cortex_m::interrupt::free(|_cs| {
        let pwm0 = unsafe { &*tm4c129x::PWM0::ptr() };
        pwm0._2_cmpa.write(|w| w.compa().bits(duty));
    });
}

#[derive(Clone, Copy, PartialEq, Eq)]
pub enum EmissionRange {
    Low,  // 22K
    Med,  // 22K//(200Ω + compensated diode)
    High  // 22K//(39Ω + uncompensated diode)
}

pub fn set_emission_range(range: EmissionRange) {
    cortex_m::interrupt::free(|_cs| {
        let gpio_p = unsafe { &*tm4c129x::GPIO_PORTP::ptr() };
        gpio_p.data.modify(|r, w| {
            let value = r.data().bits() & 0b100111;
            match range {
                EmissionRange::Low  => w.data().bits(value | 0b000000),
                EmissionRange::Med  => w.data().bits(value | 0b001000),
                EmissionRange::High => w.data().bits(value | 0b010000),
            }
        });
    });
}

#[derive(Clone, Copy, PartialEq, Eq)]
pub enum ElectrometerRange {
    Low,  // 1G
    Med,  // 1G//10M
    High  // 1G//100K
}

pub fn set_electrometer_range(range: ElectrometerRange) {
    cortex_m::interrupt::free(|_cs| {
        let gpio_p = unsafe { &*tm4c129x::GPIO_PORTP::ptr() };
        gpio_p.data.modify(|r, w| {
            let value = r.data().bits() & 0b111100;
            match range {
                ElectrometerRange::Low  => w.data().bits(value | 0b000000),
                ElectrometerRange::Med  => w.data().bits(value | 0b000001),
                ElectrometerRange::High => w.data().bits(value | 0b000010),
            }
        });
    });
}

pub fn reset_error() {
    cortex_m::interrupt::free(|_cs| {
        let gpio_q = unsafe { &*tm4c129x::GPIO_PORTQ::ptr() };
        gpio_q.data.modify(|r, w| w.data().bits(r.data().bits() & !ERR_RESN));
        gpio_q.data.modify(|r, w| w.data().bits(r.data().bits() | ERR_RESN));
    });
}

pub fn error_latched() -> bool {
    cortex_m::interrupt::free(|_cs| {
        let gpio_l = unsafe { &*tm4c129x::GPIO_PORTL::ptr() };
        gpio_l.data.read().bits() as u8 & ERR_LATCHN == 0
    })
}

pub fn process_errors() {
    let gpio_dat = cortex_m::interrupt::free(|_cs| {
        let gpio_l = unsafe { &*tm4c129x::GPIO_PORTL::ptr() };
        gpio_l.data.read().bits() as u8
    });
    if gpio_dat & FV_ERRN == 0 {
        println!("Filament overvolt");
    }
    if gpio_dat & FBV_ERRN == 0 {
        println!("Filament bias overvolt");
    }
    if gpio_dat & FBI_ERRN == 0 {
        println!("Filament bias overcurrent");
    }
    if gpio_dat & AV_ERRN == 0 {
        println!("Anode overvolt");
    }
    if gpio_dat & AI_ERRN == 0 {
        println!("Anode overcurrent");
    }
}
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

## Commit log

2017-05-04 LED access function
2017-05-04 drive both flyback PWMs
2017-05-04 use PWM functions
2017-05-04 Add FBV_PWM pin handling.
2017-05-04 add relay errata
2017-05-05 Add missing wait for GPIO ready.
    [main.rs]
2017-05-05 Add schematics.
2017-05-05 Implement ADC readout.
2017-05-06 get ADC samples as ints
2017-05-06 Report error pin status
    [main.rs]
2017-05-06 HV PID control (untested)
2017-05-06 pid: use Option instead of NaN
2017-05-06 reset error latch at startup
    [main.rs]
2017-05-06 Unbreak ADC interrupt.
2017-05-07 Make ADC actually work.
2017-05-08 Raise ADC clock to 32 MHz (maximum).
2017-05-08 some PID tuning
2017-05-08 put ADC in continuous sample mode
2017-05-08 speed up ADC
2017-05-09 Add UART debug port.
2017-05-09 print message on protection latch
2017-05-09 compute emission current, filament voltage and bias voltage
2017-05-09 average emission current samples, implement emission_ready
2017-05-10 fix resistor number in errata
2017-05-11 handle protection, print current/voltage values
2017-05-12 use PID for FV, print all debug messages
2017-05-13 adjust anode PID coefficients
2017-05-13 average more IC samples
2017-05-16 tweak emission PID parameters
2017-05-16 add missing PID update
    [loop_cathode.rs]
2017-05-31 add Gerber files
    [IONPAK1-B.Cu.gbr, IONPAK1-B.Mask.gbr, IONPAK1-B.SilkS.gbr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]
2017-05-31 update Gerber files
    [IONPAK1-B.Cu.gbr, IONPAK1-B.Mask.gbr, IONPAK1-B.SilkS.gbr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]
2017-06-08 raise threshold for switching to more sensitive IC range
2017-06-12 increase clock frequency, enable FPU correctly
    [board.rs, loop_anode.rs, loop_cathode.rs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]
2017-07-04 add mechanical drawings
    [Ionpak_1U_v5b.dxf]
2017-07-22 add PDF enclosure silkscreen drawing
2017-07-24 add missing dimension on enclosure drawing
    [Ionpak_1U_v5b1.dxf]
2017-07-24 add Kicad design files
    [IONPAK1.kicad_pcb, IONPAK1.sch]
2017-07-24 add BoM
    [ionpak_bom_rev1.xls]
2017-07-31 errata: filament flyback output diode
2017-07-31 add ethmac driver
2017-08-01 compile ethmac driver
2017-08-05 integrate ethmac/smoltcp (timestamp missing), add HTTP server
    [board.rs, main.rs]
2017-08-06 convert ADC interrupt count to milliseconds
2017-08-06 start ADC after initialization, to avoid FIFO overflows
    [board.rs, main.rs]
2017-08-06 flashed MAC address doesn't work
    [main.rs]
2017-08-06 print panic messages on UART
2017-08-06 work around ADC sample rate snafu
2017-08-07 tweak cathode PID
2017-08-07 report target filament voltage
2017-08-07 get_time_ms: ADC sampling takes NSH+12 cycles and not NSH
2017-08-07 add EEPROM driver
2017-08-07 cleanup and integrate EEPROM driver
2017-08-07 configure Ethernet LED
2017-08-07 track firmware version and expose to HTTP
2017-08-08 support resetting settings using pushbutton
    [board.rs, main.rs]
2018-01-26 Update to newer smoltcp.
    This also fixes a bug where RX descriptors would be first advanced
    and then released.
    [main.rs]
2018-02-12 add new pictures with enclosure
2018-03-08 remove broken mechanical design
    [Ionpak_1U_v5b1.dxf]
2018-03-08 add rev2 hardware design
    [IONPAK2-B.Cu.gbr, IONPAK2-B.Mask.gbr, IONPAK2-F.Cu.gbr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]
2018-03-09 add rev2 paste gerber
    [IONPAK2-F.Paste.gbr]
2018-03-09 add rev2 BoM
    [ionpak_bom_rev2.xls]
2018-03-26 Fix DMA writing to dangling pointers in ethmac.
    [main.rs]
2018-03-27 Fix signature of panic_fmt.
    [main.rs]
2018-03-27 Fix signature of panic_fmt even further.
    [main.rs]
2018-03-27 Add Cache-Control header for static assets.
    This avoids wasting device cycles on retrieving the same data over
    and over.
